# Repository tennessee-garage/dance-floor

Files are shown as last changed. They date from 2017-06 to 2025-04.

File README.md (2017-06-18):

# dance-floor
Code for various components of the LED disco dance floor

* [eagle](https://github.com/garthwebb/dance-floor/tree/master/eagle) - Eagle files for the PCBs used in this project
* [floor](https://github.com/garthwebb/dance-floor/tree/master/floor) - This code controls the light show on the dance floor
* poc_test - Proof of concept test code.
* [spi-buffer](https://github.com/garthwebb/dance-floor/tree/master/spi-buffer) - This code handles reading SPI weight data coming from the floor
* [square](https://github.com/garthwebb/dance-floor/tree/master/square) - This code run on the ATTiny in each square and manages the lights and weight sensors

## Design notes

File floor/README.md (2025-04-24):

# Floor Code



## Overview

The code in this directory controls all the lights on the floor as well as reads the weight data sent by the floor.

This code is intended to run on a Raspberry Pi with a special communication sheild that facilitates communication with the floor.  It is started via:
```bash
  python run-show.py
```
For development and testing, use the devserver driver. It allows you to run the code and preview a mock dance floor in a web browser.  It can be run via:
```bash
  python run-show.py --driver devserver
```

## Files/Directories

* **bin** - General executables
* **controller** - The main class, acts a framework for controllers and drivers
* **driver** - Different I/O drivers.  Currently they are `raspberry` for running on a Raspberry Pi and interfacing with its hardware, 'devserver' for development or `opc` (deprecated) for connecting to an existing Open GL server (`gl_server`) that simulates the floor.
* **opc-layouts** - Different OPC pixel layout files when using the opc driver.  These are used by `gl_server` to draw a representation of the floor.
* **processor** - Each file here generates different pixel patterns
* **run-show.py** - The main program that drives the dancefloor

## Setup

### Prerequisites

You'll need `poetry`. On a Mac with Homebrew, install with:

```
$ brew install poetry
```

For other options, see [the Poetry installation docs](https://python-poetry.org/docs/#installation).

### Developer setup

Install dependencies - one time, and whenever you change them:
```
$ poetry install
```

Then activate the virtual environment:
```
$ eval $(poetry env activate)
```

To run tests:

```
$ pytest
```

It is recommend you install `pre-commit` to take care of auto-formatting code.
```
$ brew install pre-commit
$ pre-commit install
```

### Production setup (Raspberry Pi)

1. Clone this repository
```bash
git clone git@github.com:tennessee-garage/dance-floor.git
```

2. [OPTIONAL] If you will run the code on a RaspberryPi, an SPI library is needed (If running in dev/virtual mode, SPI is not necessary)
```bash
git clone git@github.com:doceme/py-spidev.git
sudo apt-get install python-dev
cd py-spidev
sudo make install
```

3. Include the user that will run the code to groups that grant access to hardware ports
```bash
sudo usermod -aG spi disco
sudo usermod -aG dialout disco
```

4. Install poetry
```bash
curl -sSL https://install.python-poetry.org | python3 -
```

5. Install depencencies (from within the dance-floor repository)
```bash
cd floor
poetry install
```

## Running the code

Don't have a light up dance floor?  No problem!  You can see a visualization of the dance floor by running devserver.

1. Start the devserver:
```bash
cd floor
python run-show.py --driver devserver
```
2. Open two browser windows. The dance floor renders at this address:
   http://localhost:1979/

3. The controller renders here:
   http://0.0.0.0:1977/

## Writing a new processor

Different processors provide different ways to drive the floor LEDs. See README.md in the [processor folder](https://github.com/garthwebb/dance-floor/tree/master/floor/processor) for how to write a new processor.

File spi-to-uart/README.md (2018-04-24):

# SPI to UART

This is a simple program to read data coming in on SPI and transmit the data directly to UART.  It is unidirectional,
so does not read data from UART.  The data is not interpreted either.  it is transmitted byte by byte exactly as it
is received.

This is used to read the SPI values the squares are sending, and then send it out to an FTDI cable connected to a
computer.  If I wasn't too lazy to find and power up a Raspberry Pi I could probably write a script to read the SPI
port directly and print to terminal.

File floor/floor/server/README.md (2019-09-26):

# Dancefloor Server

This is a simple HTTP service that exposes a public API and control web page to the running dance floor. It also exposes a GUI control interface.

<!-- START doctoc generated TOC please keep comment here to allow auto update -->
<!-- DON'T EDIT THIS SECTION, INSTEAD RE-RUN doctoc TO UPDATE -->
**Table of Contents**  *generated with [DocToc](https://github.com/thlorenz/doctoc)*

- [GUI Frontend](#gui-frontend)
- [API](#api)
  - [`GET /api/status`](#get-apistatus)
  - [`POST /api/playlist/advance`](#post-apiplaylistadvance)
  - [`POST /api/playlist/previous`](#post-apiplaylistprevious)
  - [`POST /api/playlist/add`](#post-apiplaylistadd)
  - [`POST /api/playlist/stay`](#post-apiplayliststay)
  - [`DELETE /api/playlist/:position`](#delete-apiplaylistposition)
  - [`GET /api/playlists`](#get-apiplaylists)
  - [`GET /api/playlists/:name`](#get-apiplaylistsname)
  - [`POST /api/playlists/:name`](#post-apiplaylistsname)
  - [`POST /api/playlists/:name/activate`](#post-apiplaylistsnameactivate)
  - [`GET /api/tempo`](#get-apitempo)
  - [`POST /api/tempo`](#post-apitempo)
  - [`POST /api/tempo/nudge`](#post-apitemponudge)
  - [`GET /api/brightness`](#get-apibrightness)
  - [`POST /api/brightness`](#post-apibrightness)
  - [`GET /api/layers/:name`](#get-apilayersname)
  - [`PATCH /api/layers/:name`](#patch-apilayersname)
- [TODO](#todo)

<!-- END doctoc generated TOC please keep comment here to allow auto update -->

## GUI Frontend

The frontend is developed in a separate project. See source here: https://github.com/tennessee-garage/ddfui

For "production", we periodically check in a snapshot of this frontend to the `./static` folder here, so the RPi can serve it directly. These are the rough steps to follow:

```
### Build "production" frontend js, css, and assets.

$ cd ~/git/ddfui
$ npm install
$ yarn build

### Copy the built assets into this project.

$ cd ~/git/dance-floor/floor
$ ./bin/sync-frontend.sh ~/git/ddfui/build/
```

## API

### `GET /api/status`

Returns the current status.

**Request Arguments**

None.

**Response**

A structure consisting of:

* `playlist` (object): The current playlist; see `GET /api/playlist`.
* `tempo` (object): The current tempo; see `GET /api/tempo`.
* `processors` (array): A list of available processor, each an object consisting of:
  * `name` (string): The name of the processor.
* `brightness` (number): The global brightness, a number on `0.0 - 1.0`.

```json
{
  "playlist": {
    "current_position": 1,
    "millis_remaining": 2106,
    "queue": [
      {
        "args": {
          "animation": "Color train"
        },
        "duration": 5,
        "name": "animator"
      },
      {
        "args": {
          "text": "Bleep bloop fazz!"
        },
        "duration": 5,
        "name": "message"
      },
    ]
  },
  "processors": {
    "animator": {
      "name": "animator"
    },
    "message": {
      "name": "message"
    },
    "pulsar": {
      "name": "pulsar"
    }
  },
  "layers": {
    "overlay1": {
      "enabled": true,
      "processor_name": "CoolStep"
    },
    "overlay2": {
      "enabled": false,
      "processor_name": null
    }
  },
  "tempo": {
    "bpm": 120.0,
    "downbeat_millis": 1500861666019
  }
}```

### `GET /api/playlist`

Returns the current playlist.

**Request Arguments**

None.

**Response**

A playlist structure, consisting of:

* `current_position` (number): Current playlist position.
* `millis_remaining` (number): Number of milliseconds remaining on current item, `0` for indefinite.
* `queue` (object): The complete playlist, each item consisting of:
  * `name` (string): The processor name.
  * `duration` (number): The play duration, `0` for indefinite.
  * `args` (object; optional): Arguments to the processor.

```json
{
    "current_position": 1,
    "current": {
        "name": "message",
        "args": {
            "text": "Bleep bloop fazz!"
        },
        "duration": 5
    },
    "queue": [
        {
            "args": {
                "animation": "Color train"
            },
            "duration": 5,
            "name": "animator"
        },
        {
            "args": {
                "text": "Bleep bloop fazz!"
            },
            "duration": 5,
            "name": "message"
        },
        {
            "args": null,
            "duration": 5,
            "name": "raver_plaid"
        }
    ],
    "millis_remaining": 1492
}
```

### `POST /api/playlist/advance`

Advances the playlist to the next item, returning the playlist object.

**Request arguments**

None.

**Response**

The playlist object.

### `POST /api/playlist/previous`

Moves the playlist to the previous item, returning the playlist object.

**Request arguments**

None.

**Response**

The playlist object.

### `POST /api/playlist/add`

Adds a new item to the playlist, at the end of the playlist.

**Request arguments**

* `name` (string): The processor name.
* `duration` (number; optional): Play time in seconds; default of `0` for indefinite.
* `args` (string; optional): Processor-specific arguments.
* `next` (boolean; optional): If `true`, insert in next position rather than end. Implied when `immediate = true`.
* `immediate` (boolean; optional): If `true`, insert in next position _and_ advance immediately.

**Response**

The playlist object upon success; HTTP `400` on error.

### `POST /api/playlist/stay`

Cancel any auto-advance timeout on the current playlist item ("stay" on this processor).

**Request arguments**

None.

**Response**

The playlist object.

### `DELETE /api/playlist/:position`

Remove the playlist item at position `position`.

**Request arguments**

None.

**Response**

The playlist object upon success; HTTP `400` on error.

### `GET /api/playlists`

Lists _all_ playlists known to the system.

**Request arguments**

None.

**Response**

A dictionary of playlist items, keyed by a slug-like playlist name. Each value has the same format as `GET /api/playlist`.

### `GET /api/playlists/:name`

Fetches a single playlist, by slug-like playlist name.

**Request arguments**

None.

**Response**

The playlist object upon success; HTTP `404` if not found.

### `POST /api/playlists/:name`

Creates or updates a single playlist, by slug-like playlist name.

**Request arguments**

The request body should be a well-formed playlist object.

**Response**

The playlist object upon success; HTTP `400` upon failure.

### `POST /api/playlists/:name/activate`

Set this playlist as the current playlist.

**Request arguments**

None.

**Response**

The playlist object upon success; HTTP `404` if not found.

### `GET /api/tempo`

Get the current tempo settings.

**Request arguments**

None.

**Response**

The BPM information, consisting of:

* `bpm` (number): Beats per minute.
* `downbeat_millis` (number): Timestamp in milliseconds of the downbeat.

### `POST /api/tempo`

Set the current tempo.

**Request arguments**

* `bpm` (number): Beats per minute, as a number

**Response**

The BPM information.

### `POST /api/tempo/nudge`

Shift the BPM, downbeat, or both by a relative amount

**Request arguments**

* `bpm_delta` (number; optional): Value to add to or subtract from the current bpm.
* `downbeat_millis_delta` (number; optional): Value to add to or subtract from the current downbeat.

**Response**

The BPM information.

### `GET /api/brightness`

Get the global brightness of the floor, on a scale of 0.0 to 1.0.

**Response**

The current brightness.

```json
{
  "brightness": 0.7
}
```

### `POST /api/brightness`

Change the global brightness of the floor, on a scale of 0.0 to 1.0.

**Request arguments**

* `brightness` (number): The desired brightness, on a scale of `0.0` to `1.0`.

**Response**

Same as `GET /api/brightness`

### `GET /api/layers/:name`

Get details about a rendering layer.

**Response**

The layer's details.

```json
{
  "enabled": true,
  "processor_name": "CoolStep"
}
```

### `PATCH /api/layers/:name`

Adjust a rendering layer. Currently supports changing the processor, by patching the `processor_name` field.

**Request arguments**

* `processor_name` (string): The new processor name, or empty string to select no processor.
* `enabled` (boolean): Whether or not to enable the layer.

**Response**

Same as `GET /api/layers/:name`.

## TODO

Some improvements which should be made:

* Use a wsgi server in "production".
* Common error handling.
* Threadsafety around `Playlist` actions.
* Implement "add" and "delete" playlist operations.

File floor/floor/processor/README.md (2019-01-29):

# Processor Code

## Creating a new processor

1. Start with the skeleton for a processor:
```python
from floor.processor.base import Base

class YourPattern(Base):

    def __init__(self, **kwargs):
        super(YourPattern, self).__init__(**kwargs)
        # Set/initialize any state variables here

    def get_next_frame(self, context):
        # This gets called once every 1/fps seconds

        # Do something with list of context.weight values

        # Compute a list of RGB tuples, limit by COLOR_MAXIMUM
        # which gets set for you based on driver at object creation

        return pixels
```
2. Create code in `gen_next_frame` that creates a single frame of 64 RGB values.  The dance floor is 8 x 8 so if you want to work with x and y coordinates, you can do `pixels[x + y*8]` to index into the array as if it were multidimensional.
3. Import the processor in `processor/__init__.py`.
4. To test, call your class from the command line by giving the file name (make sure [gl_sever is running](https://github.com/garthwebb/dance-floor/blob/master/floor/README.md#running-the-code)):
```bash
python run-show.py --driver opc --processor your_class_file
```

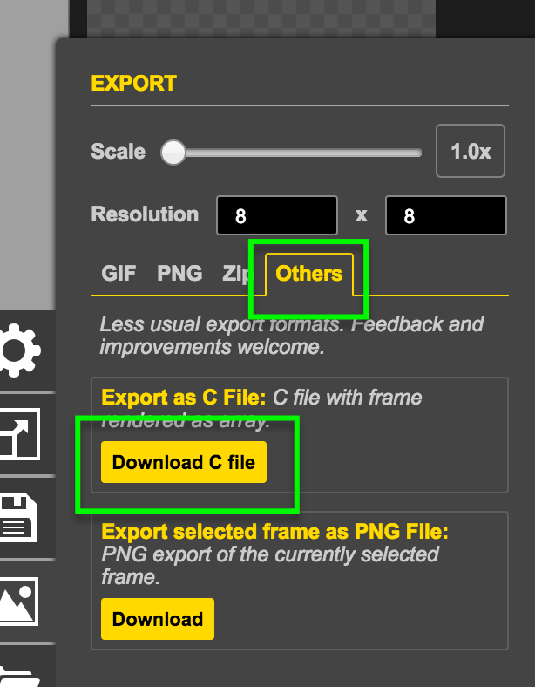
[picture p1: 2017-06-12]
wiki/img/Export C.png

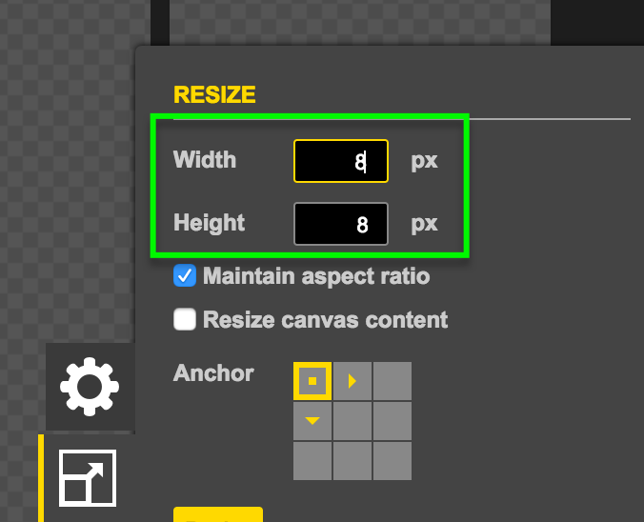
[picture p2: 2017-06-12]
wiki/img/Size-screenshot.png

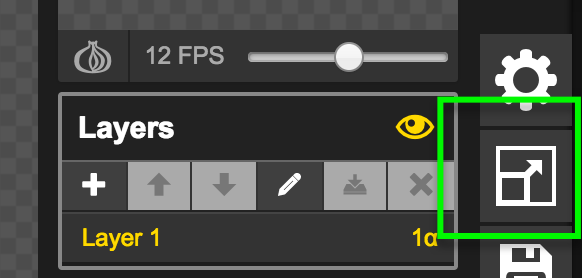
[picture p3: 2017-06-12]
wiki/img/Resize-screenshot.png

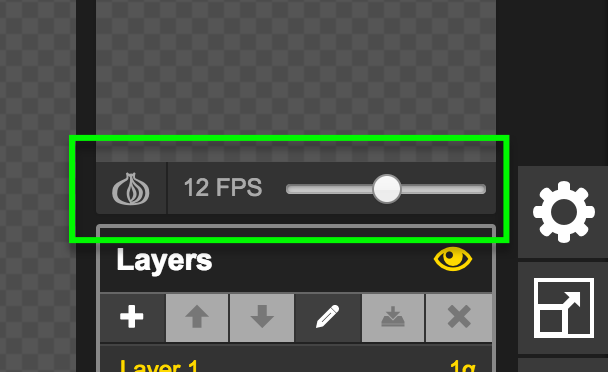
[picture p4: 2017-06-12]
wiki/img/fps-screenshot.png

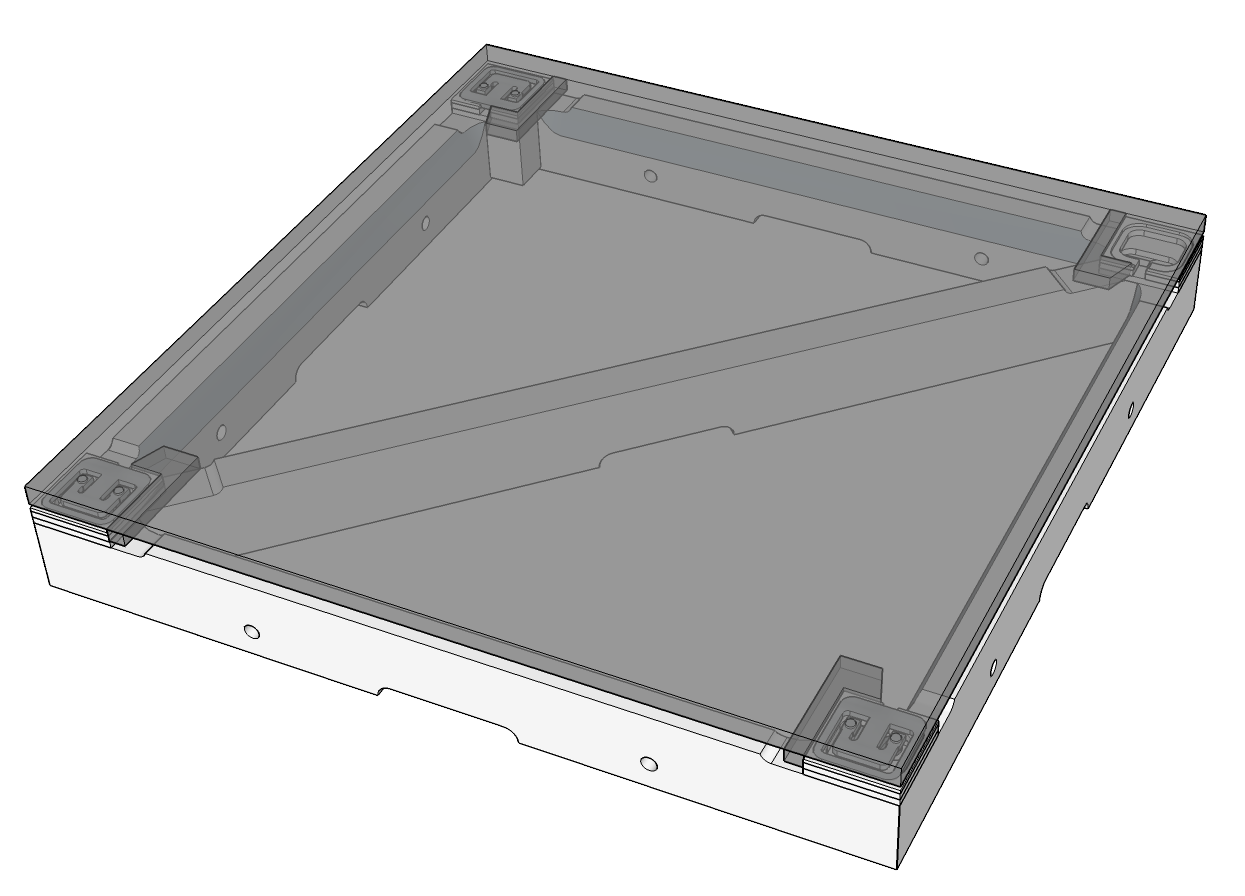
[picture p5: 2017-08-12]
models/Tile.png

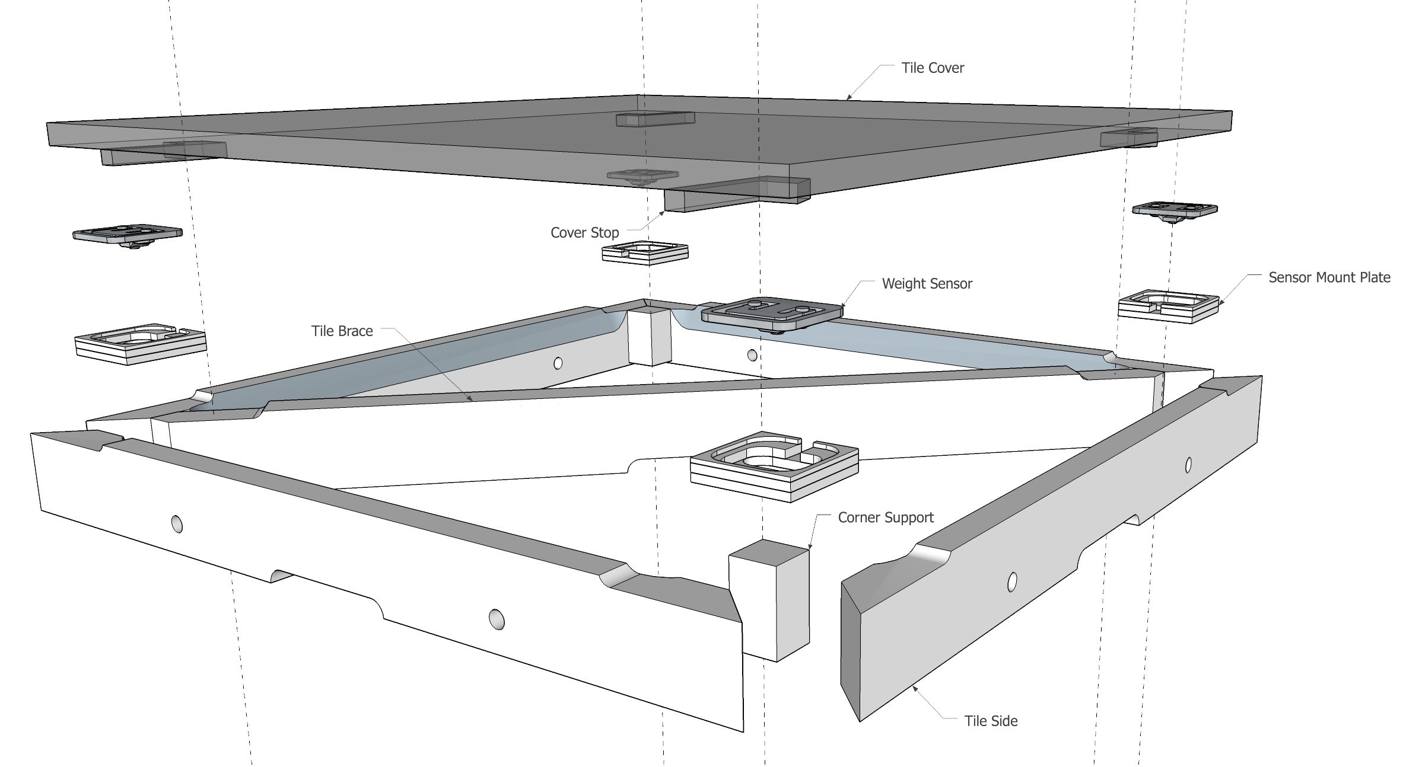
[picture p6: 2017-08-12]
models/Exploded View Tile.png

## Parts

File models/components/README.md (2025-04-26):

# 3D Models #

The *.skp files are models that were created in Sketchup of the different floor components.

The *.stl files are exports of these files from Sketchup, and can be previewed directly in Github, whereas the *.skp files will just be data/garbage

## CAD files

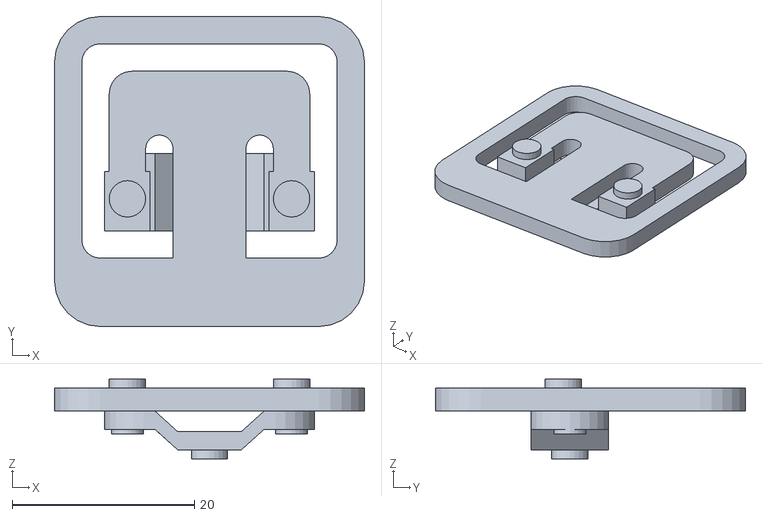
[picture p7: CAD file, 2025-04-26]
models/components/Weight Sensor.stl
34.0 x 34.0 x 8.75

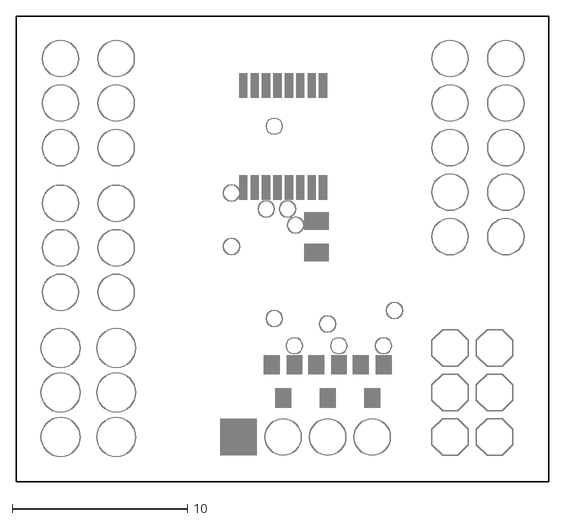
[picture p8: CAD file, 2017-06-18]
pcb/tile-controller/tile-controller-bottom.dxf
30.4 x 26.5

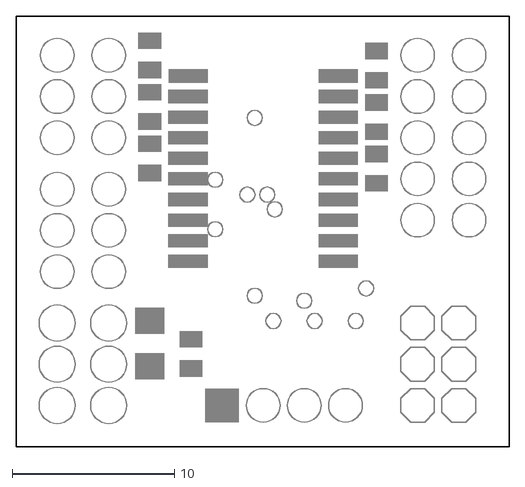
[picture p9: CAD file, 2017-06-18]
pcb/tile-controller/tile-controller.dxf
30.4 x 26.5

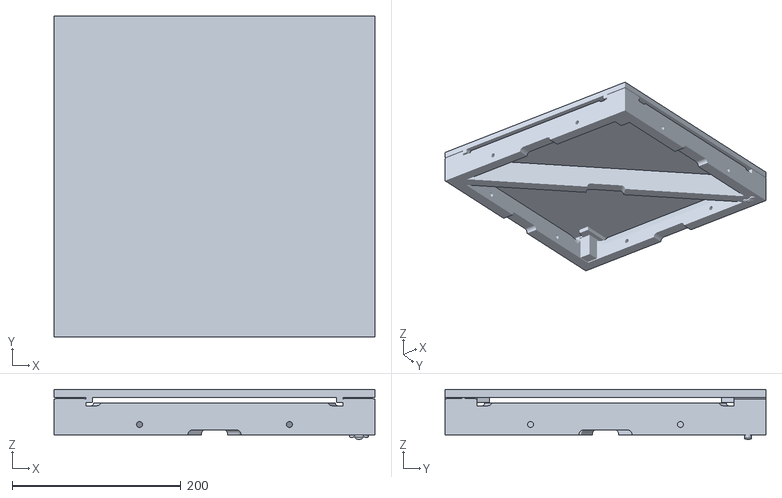
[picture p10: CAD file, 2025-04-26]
models/components/Single Tile.stl
381.0 x 381.0 x 59.7

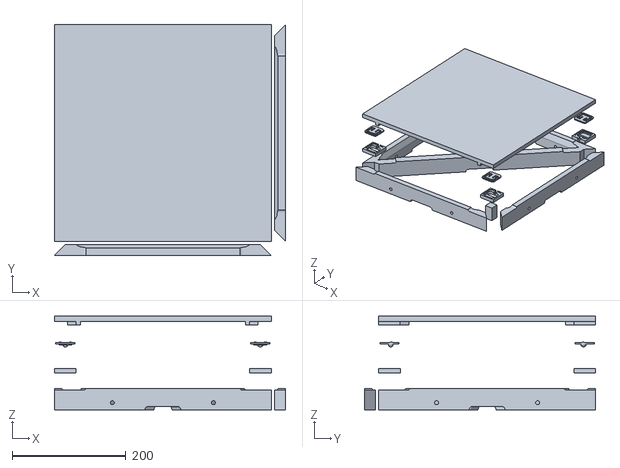
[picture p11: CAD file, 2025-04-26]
models/components/Exploded View Tile.stl
406.0 x 406.0 x 165.0

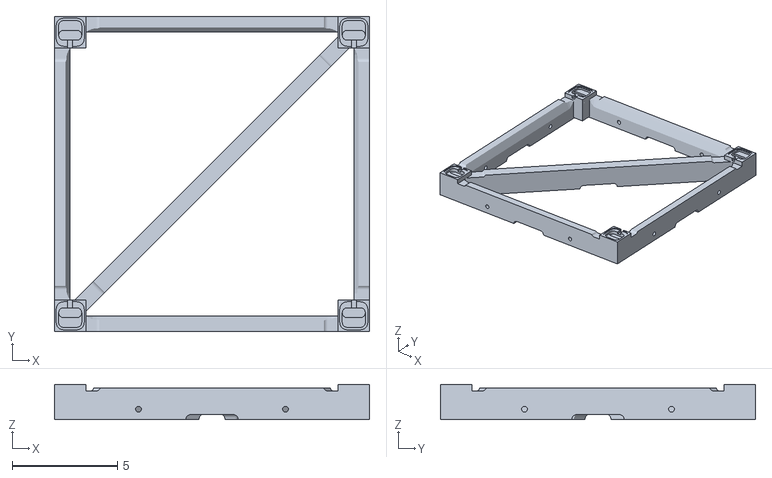
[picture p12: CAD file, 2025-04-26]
models/components/Tile Base.stl
15.0 x 15.0 x 1.69

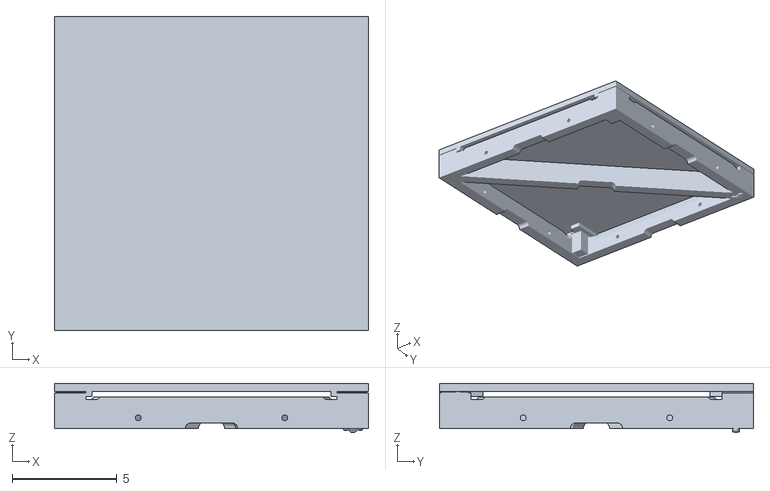
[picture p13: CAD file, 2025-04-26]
models/components/Tile.stl
15.0 x 15.0 x 2.35

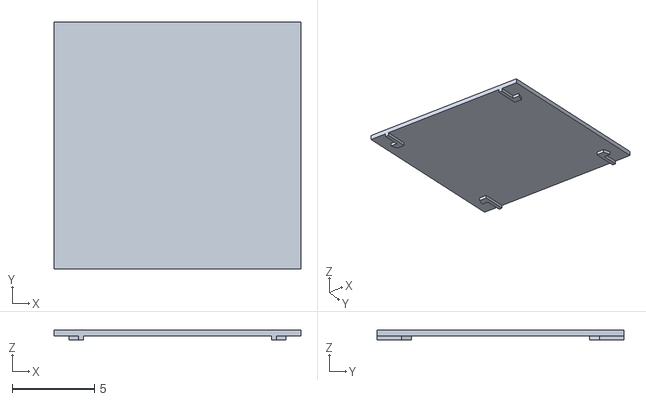
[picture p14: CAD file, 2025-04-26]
models/components/Tile Cover.stl
15.0 x 15.0 x 0.625

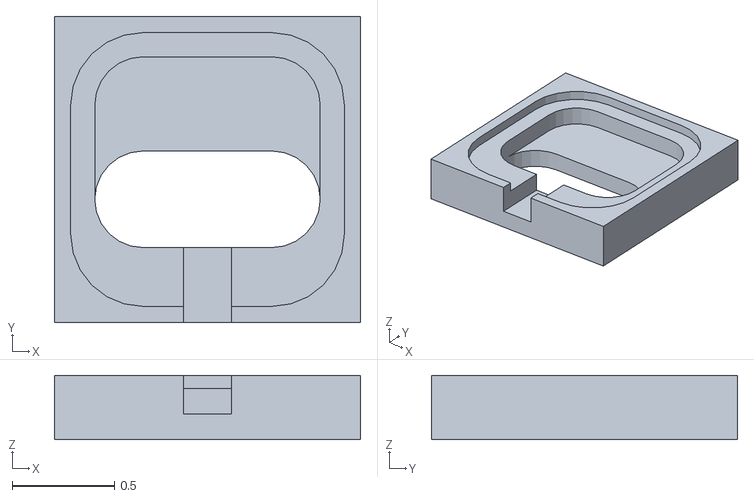
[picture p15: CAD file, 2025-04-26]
models/components/Weight Support.stl
1.50 x 1.50 x 0.313

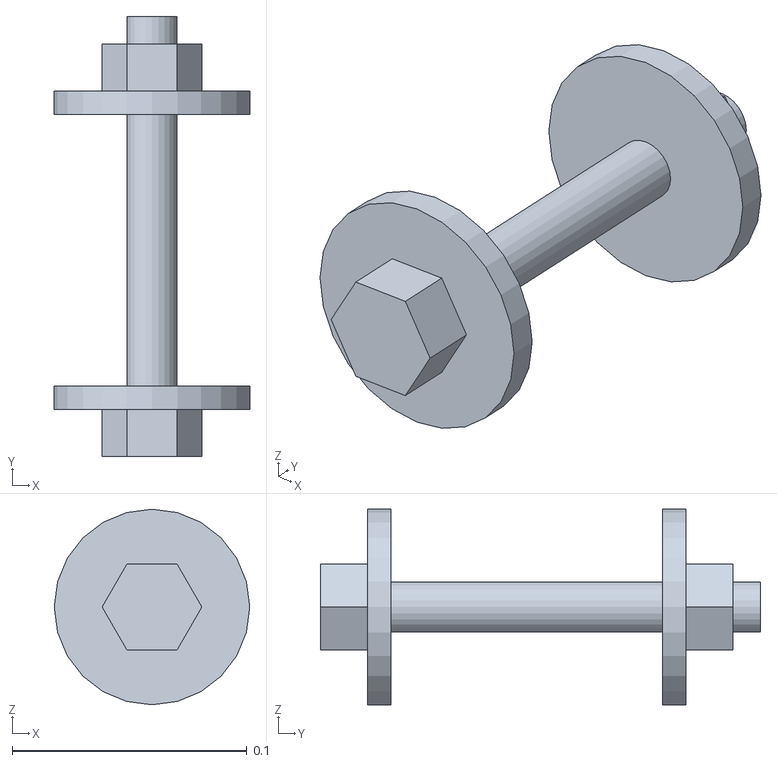
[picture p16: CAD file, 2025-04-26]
models/components/Hardware 1.4 Nuts Bolts Adjustable Length.stl
0.0833 x 0.187 x 0.0833

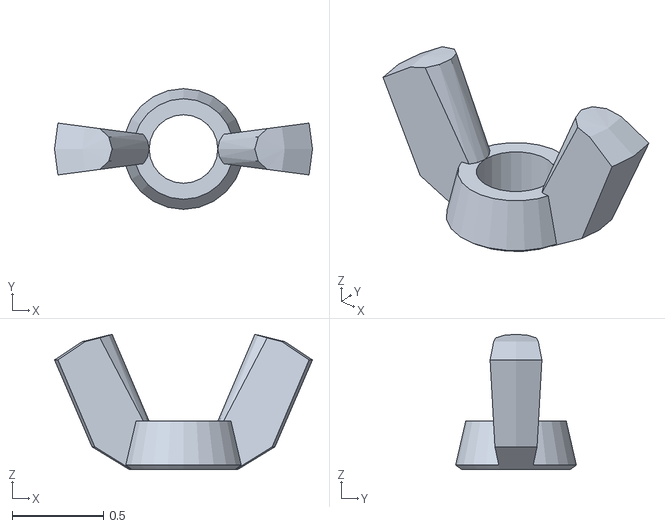
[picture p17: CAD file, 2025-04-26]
models/components/Wing Nut.stl
1.41 x 0.66 x 0.74

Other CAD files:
pcb/comm-board/comm-board.dxf
models/Floor Assembly.skp
models/Power Distribution.skp
models/components/Exploded View Tile.skp
models/components/Hardware 1.4 Nuts Bolts Adjustable Length.skp
models/components/Single tile.skp
models/components/Tile Base.skp
models/components/Tile Cover.skp
models/components/Tile.skp
models/components/Weight Sensor.skp
models/components/Weight Support.skp
models/components/Wing Nut.skp

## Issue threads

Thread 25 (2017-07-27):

Playlist management from web UI

mik3y, 2017-07-27:
(Filing this for tracking as I've got a branch in progress & would like to hear if I'm missing anything!)

Should be able to:
* List and add a new item from existing processors.
* Set optional args (like `text` for `message`).
* Set duration or infinite.
* Delete a playlist item.
* Reset to default state.

Playlist UI should also show a duration indicator for current item.

Closed 2019-09-26.

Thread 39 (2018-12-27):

Processor interface pixel format change?

mik3y, 2018-12-27:
Currently processors return pixels as a 3-tuple of `(red, green, blue)`, which are integers on `[0, self.max_value]`. `self.max_value` is a dynamic value within a processor, which can vary based on (a) the dynamic range of the show's driver, and (b) the current brightness called for by the controller.

I was thinking both (a) and (b) are leaky abstractions of sorts, since they're controller concepts that a "generic" processor shouldn't have to worry about. We could simplify processor code by moving these back to an unchanging absolute range, like `[0-255]` for 8-bit color.

As an unrelated thought, I also thought in the future it might be really interesting to support a mode where you can "stack" or layer processors, similar to e.g. layers in photoshop, where an alpha channel describes how much of the next layer beneath to blend.

Both of these combined: What do you think about changing the "pixel" return value to something like an absolute `(red, greed, blue, alpha)`; and consequently, move scaling currently accomplished by `max_value` into the `Controller`?

mik3y, 2018-12-27:
not sure if you get notifications on issue create, so just in case: yo @garthwebb !

mik3y, 2018-12-28:
Oh, a slight tweak on this idea, we could support _either_ 4-tuple `(r, g, b, a)` pixels, or 3-tuple `(r, g, b)` with implied alpha of 100% (for processors that don't care about alpha). In either case, r/g/b/a would all be on a standard range as in the other part of the proposal, like `[0.0, 1.0]` or `[0, 255]`.

garthwebb, 2018-12-28:
So the driver class _should_ be the thing that dictates what the max value is, and in fact it is, but it's plumbed through in a weird way right now.  Having the `max_value` field set and defined within the `Base` processor class is meant to make it so the 'processor shouldn't have to worry about' it.

I think the Base.__init__ should take a controller object and then `Base.max_value()` asks the controller what the max value is (rather than Controller pushing the value out to the processor as current).  The `Controller` should get its value from the `Driver` and modify it depending on the input it gets about dimming the floor.

I don't want to limit us to 8-bit color channels because it just can't do good fades since you get at best 256 steps if starting from full on.  Even then, the human eye is much more perceptive to lower luminosity levels, so it works out to ~128 steps (the top 128 you don't really notice).

I know we could get that back with the alpha channel, but that would only come into play for Processors that want to intentionally dim.  For processors that are varying in color over time the effect will be noticeable chunkiness at lower light levels.

If we really wanted to have a constant value for Processors, I'd advocate for 0.0 to 1.0 and then do the math to scale up in the driver.  However, I'd worry if the little RaspberryPi could handle 196 additional floating point calculations per frame.  Already with the Ripple pattern requesting 120 fps (it does look better) when running on the RaspPi it can't finish a frame in time.  As a side note, I think it would be good to make a performance pass at some point.

Finally, another angle to take if we start messing with pixel representation is to go to HSV.  We need RGB simply because it's the physical representation of the lighting, but its garbage to work with in Processors.  Almost always, you just want a color and you want to vary that color in a sane way.  Mixing R, G, B is not sane.

mik3y, 2018-12-29:
Ah, great points!

> If we really wanted to have a constant value for Processors, I'd advocate for 0.0 to 1.0 and then do the math to scale up in the driver. However, I'd worry if the little RaspberryPi could handle 196 additional floating point calculations per frame. Already with the Ripple pattern requesting 120 fps (it does look better) when running on the RaspPi it can't finish a frame in time. As a side note, I think it would be good to make a performance pass at some point.

My thoughts as well! One of the things I've wanted to do for a while is benchmark some of the existing processors, especially before making changes that could affect (or are suspected to improve) performance. Some of my recent changes to inject the clock now make this a lot easier (since we can call `get_next_frame` as fast as we want, with a fake clock)... lemme pause on the pixel idea here, write the benchmarker, and then see where we end up.

mik3y, 2019-05-25:
implemented in #46 - closing!

Closed 2019-05-25.

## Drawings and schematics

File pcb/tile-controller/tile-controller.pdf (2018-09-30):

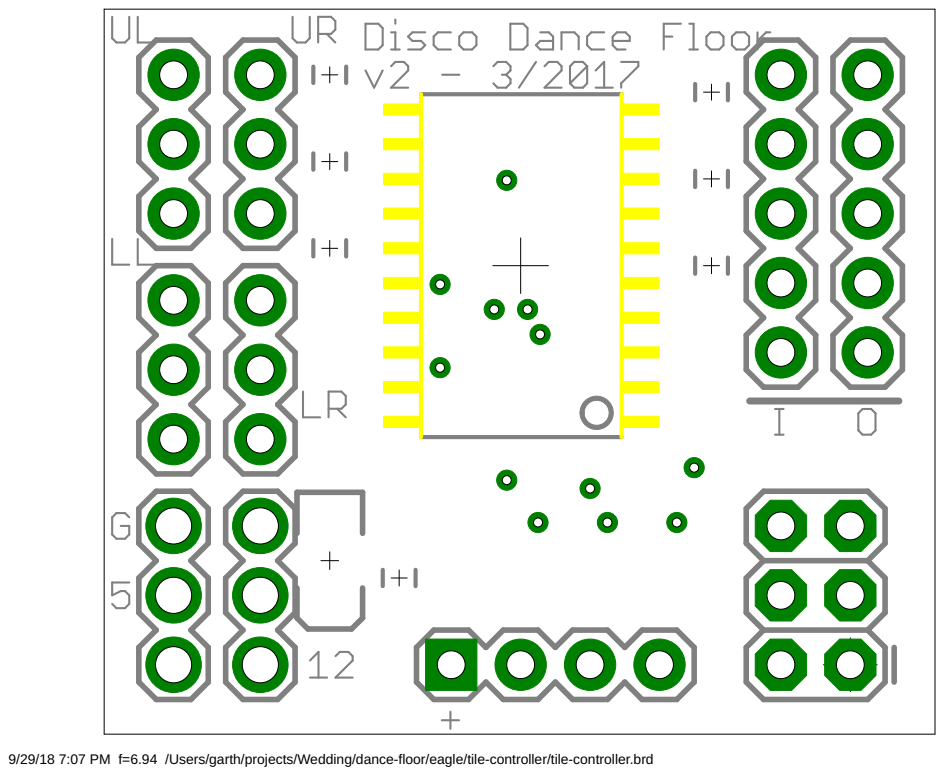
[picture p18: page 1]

9/29/18 7:07 PM f=6.94 /Users/garth/projects/Wedding/dance-floor/eagle/tile-controller/tile-controller.brd

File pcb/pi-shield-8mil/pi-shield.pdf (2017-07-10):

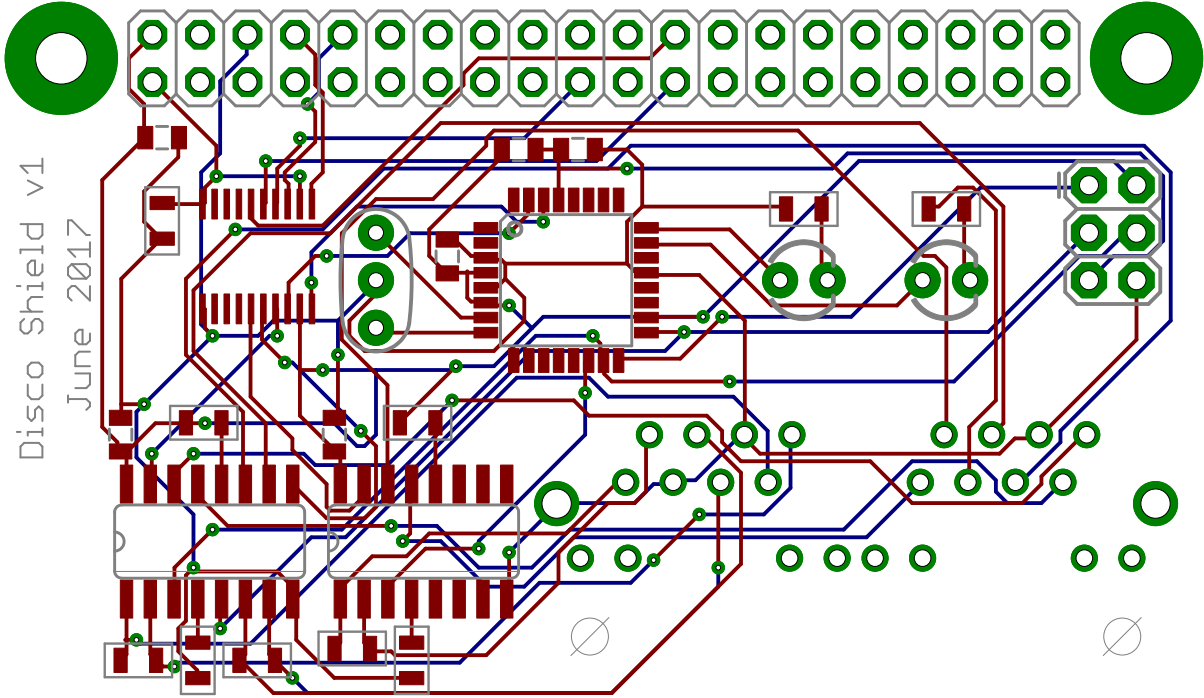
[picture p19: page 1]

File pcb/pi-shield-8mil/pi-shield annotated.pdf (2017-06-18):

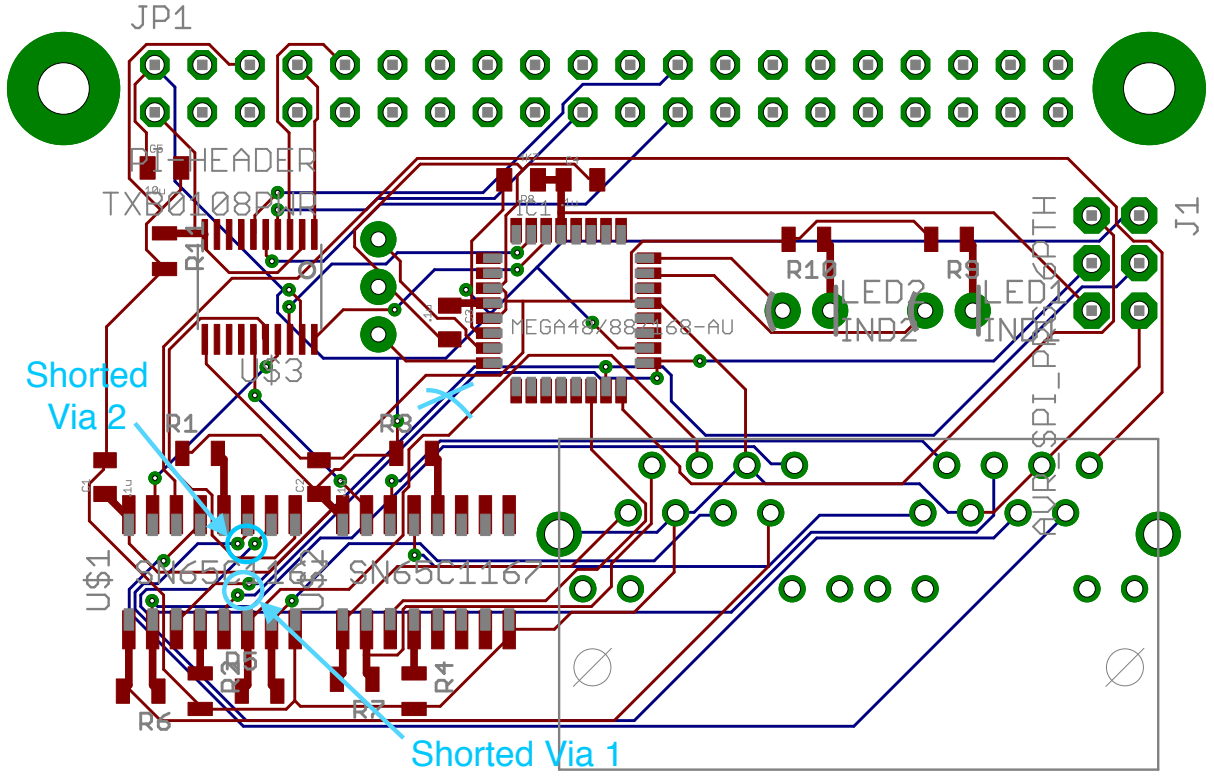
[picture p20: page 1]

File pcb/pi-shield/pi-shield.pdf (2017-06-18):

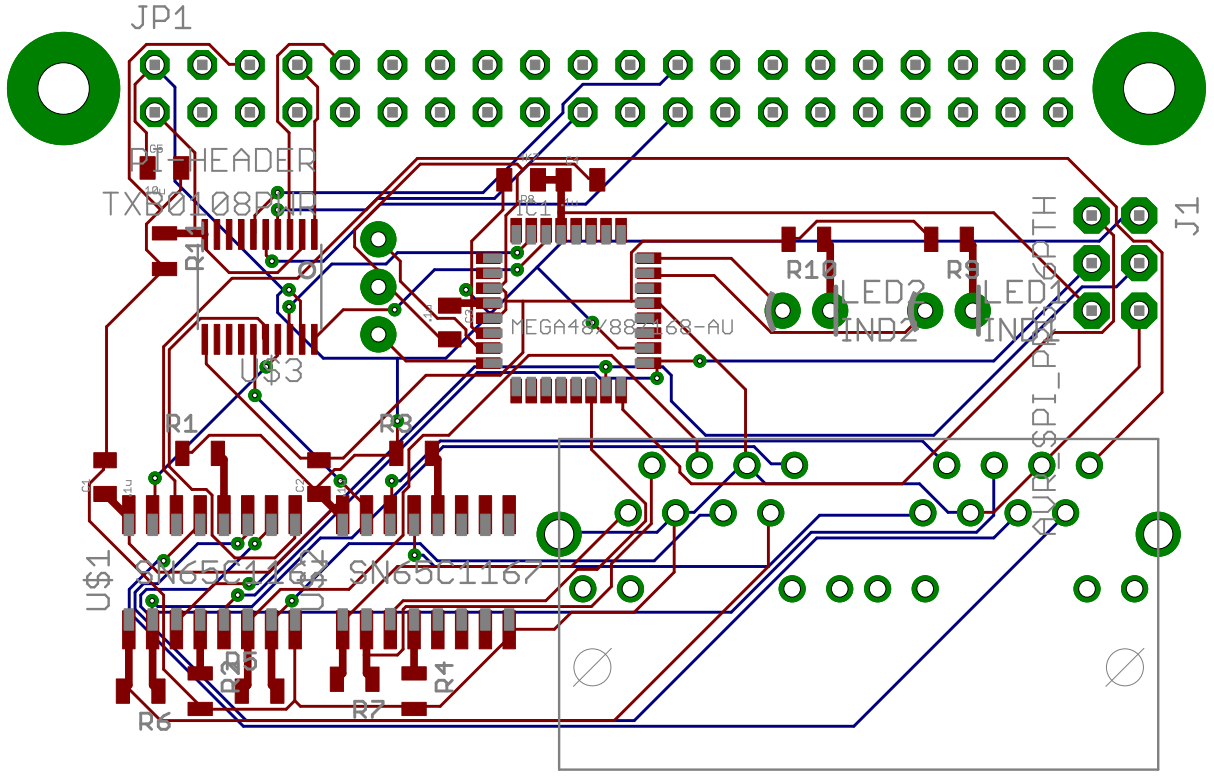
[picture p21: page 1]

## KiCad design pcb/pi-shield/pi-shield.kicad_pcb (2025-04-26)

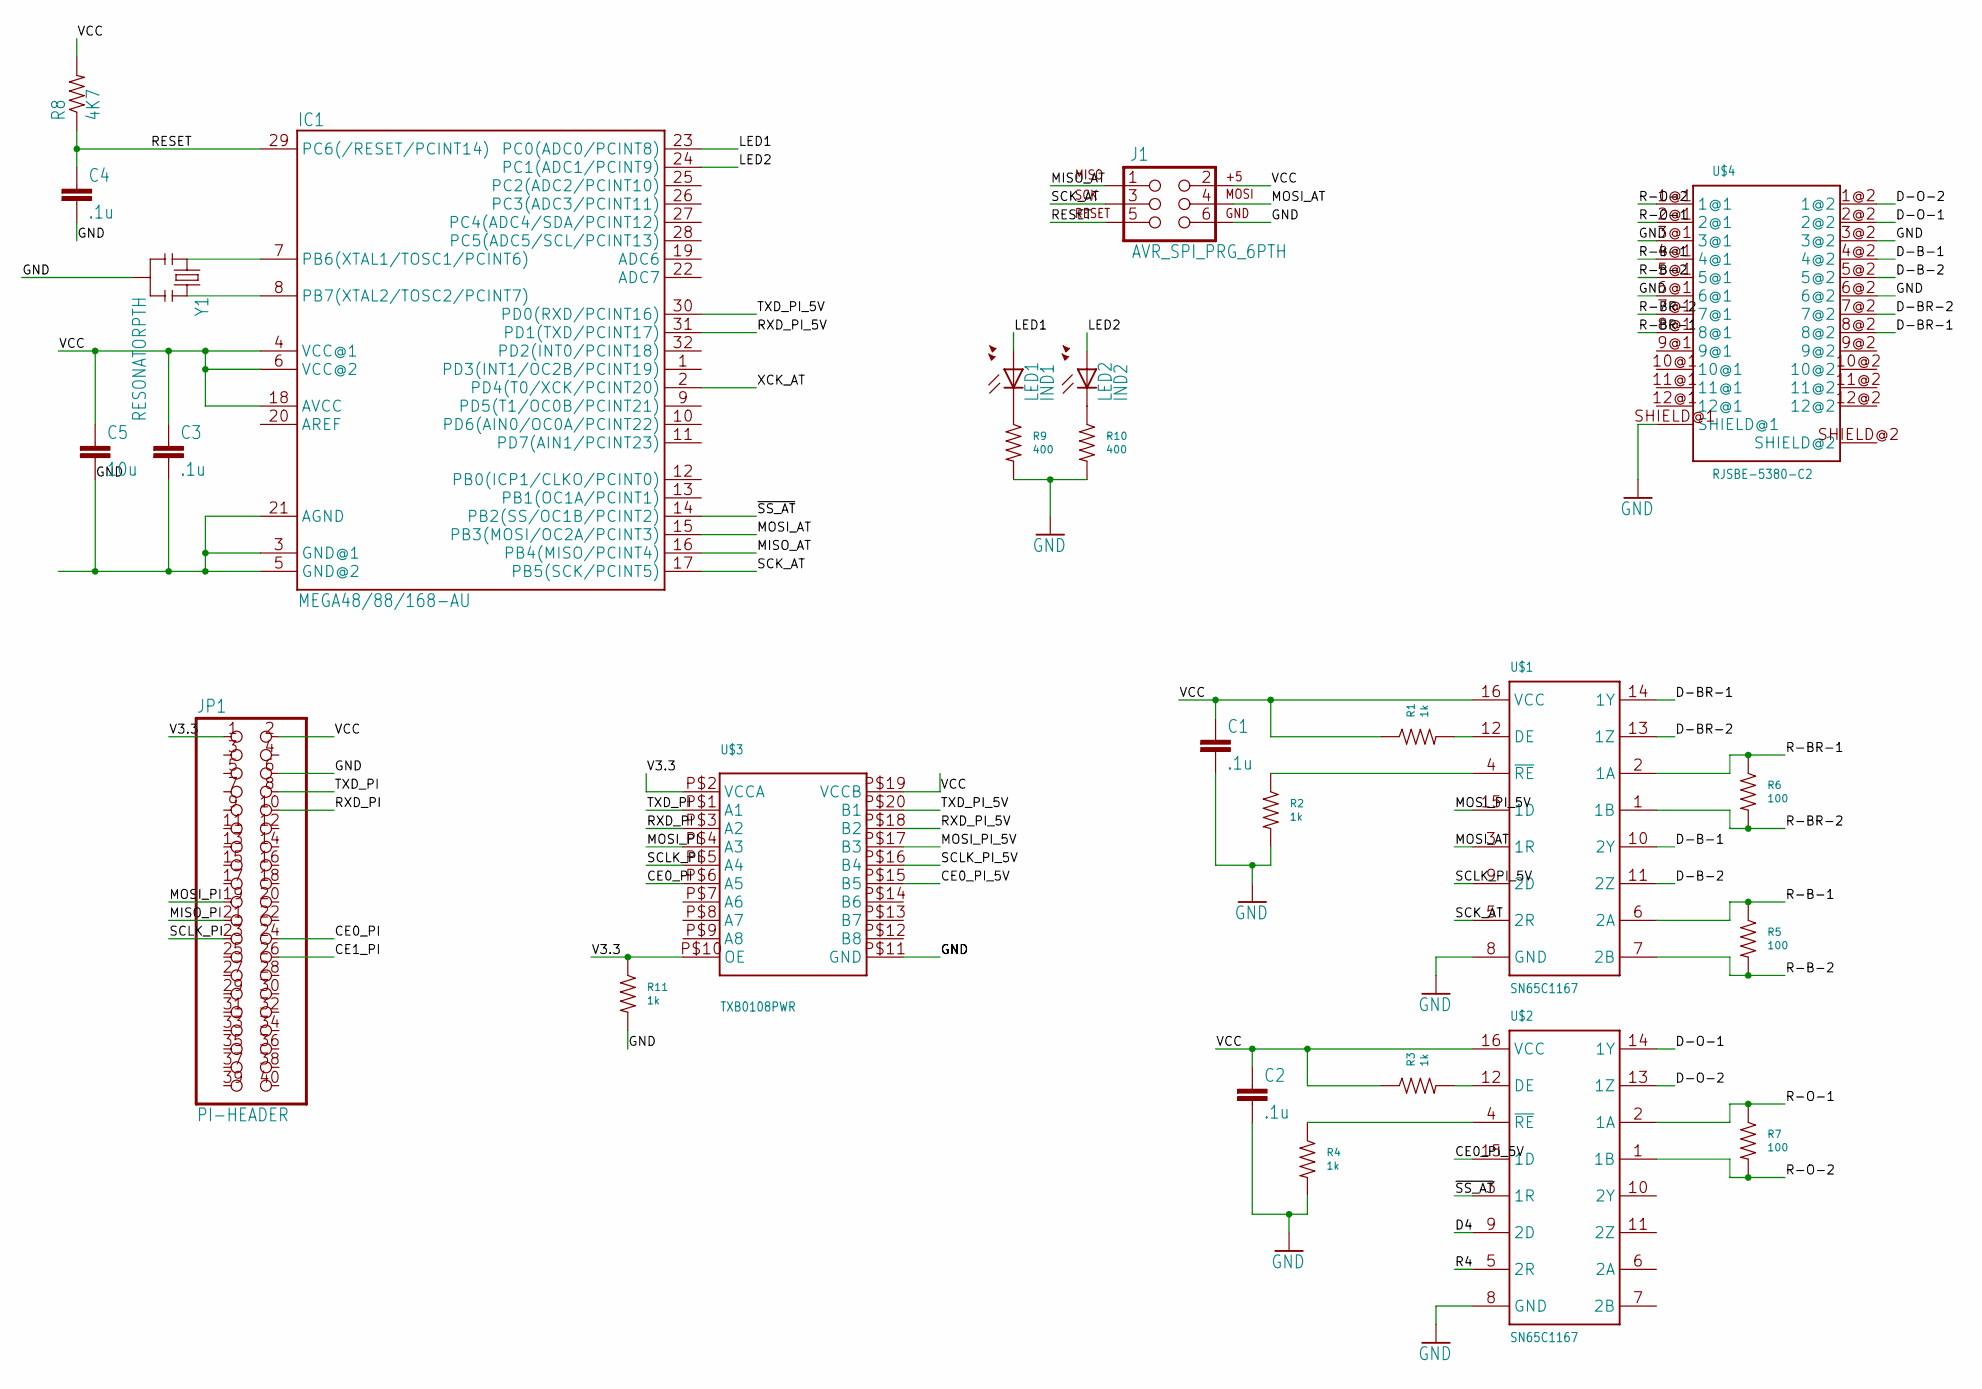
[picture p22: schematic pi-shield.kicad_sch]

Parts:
C1, C2, C3, C4: .1u; 0805
C5: 10u; 0805
IC1: MEGA48/88/168-AU; TQFP32-08
J1: AVR_SPI_PRG_6PTH; 2X3
JP1: PI-HEADER; 2X20
LED1: IND1; LED3MM
LED2: IND2; LED3MM
R1, R2, R3, R4, R11: 1k; R0805
R5, R6, R7: 100; R0805
R8: 4K7; 0805
R9, R10: 400; R0805
U$1, U$2: SN65C1167; SOP-16
U$3: TXB0108PWR; TSSOP20
U$4: RJSBE-5380-C2
Y1: RESONATORPTH; RESONATOR-PTH

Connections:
CE0_PI: JP1.24, U$3.P$6 (A5)
CE0_PI_5V: U$2.15 (1D), U$3.P$15 (B5)
CE1_PI: JP1.26
D4: U$2.9 (2D)
D-B-1: U$1.10 (2Y), U$4.4@2
D-B-2: U$1.11 (2Z), U$4.5@2
D-BR-1: U$1.14 (1Y), U$4.8@2
D-BR-2: U$1.13 (1Z), U$4.7@2
D-O-1: U$2.14 (1Y), U$4.2@2
D-O-2: U$2.13 (1Z), U$4.1@2
GND: C1.2, C2.2, C3.2, C4.2, C5.2, IC1.3 (GND@1), IC1.5 (GND@2), IC1.21 (AGND), J1.6, JP1.6, R2.P$2, R4.P$2, R9.P$2, R10.P$2, R11.P$2, U$1.8 (GND), U$2.8 (GND), U$3.P$11 (GND), U$4.3@1, U$4.3@2, U$4.6@1, U$4.6@2, U$4.SHIELD@1, Y1.2
LED1: IC1.23 (PC0(ADC0/PCINT8)), LED1.A
LED2: IC1.24 (PC1(ADC1/PCINT9)), LED2.A
MISO_AT: IC1.16 (PB4(MISO/PCINT4)), J1.1
MISO_PI: JP1.21
MOSI_AT: IC1.15 (PB3(MOSI/OC2A/PCINT3)), J1.4, U$1.3 (1R)
MOSI_PI: JP1.19, U$3.P$4 (A3)
MOSI_PI_5V: U$1.15 (1D), U$3.P$17 (B3)
unnamed: R1.P$2, U$1.12 (DE)
unnamed: R2.P$1, U$1.4 (~RE)
unnamed: R3.P$2, U$2.12 (DE)
unnamed: R4.P$1, U$2.4 (~RE)
unnamed: LED1.K (C), R9.P$1
unnamed: LED2.K (C), R10.P$1
unnamed: IC1.7 (PB6(XTAL1/TOSC1/PCINT6)), Y1.1
unnamed: IC1.8 (PB7(XTAL2/TOSC2/PCINT7)), Y1.3
R4: U$2.5 (2R)
R-B-1: R5.P$1, U$1.6 (2A), U$4.4@1
R-B-2: R5.P$2, U$1.7 (2B), U$4.5@1
R-BR-1: R6.P$1, U$1.2 (1A), U$4.8@1
R-BR-2: R6.P$2, U$1.1 (1B), U$4.7@1
R-O-1: R7.P$1, U$2.2 (1A), U$4.2@1
R-O-2: R7.P$2, U$2.1 (1B), U$4.1@1
RESET: C4.1, IC1.29 (PC6(/RESET/PCINT14)), J1.5, R8.1
RXD_PI: JP1.10, U$3.P$3 (A2)
RXD_PI_5V: IC1.31 (PD1(TXD/PCINT17)), U$3.P$18 (B2)
SCK_AT: IC1.17 (PB5(SCK/PCINT5)), J1.3, U$1.5 (2R)
SCLK_PI: JP1.23, U$3.P$5 (A4)
SCLK_PI_5V: U$1.9 (2D), U$3.P$16 (B4)
TXD_PI: JP1.8, U$3.P$1 (A1)
TXD_PI_5V: IC1.30 (PD0(RXD/PCINT16)), U$3.P$20 (B1)
V3.3: JP1.1, R11.P$1, U$3.P$2 (VCCA), U$3.P$10 (OE)
VCC: C1.1, C2.1, C3.1, C5.1, IC1.4 (VCC@1), IC1.6 (VCC@2), IC1.18 (AVCC), J1.2, JP1.2, R1.P$1, R3.P$1, R8.2, U$1.16 (VCC), U$2.16 (VCC), U$3.P$19 (VCCB)
XCK_AT: IC1.2 (PD4(T0/XCK/PCINT20))
~SS_AT: IC1.14 (PB2(SS/OC1B/PCINT2)), U$2.3 (1R)

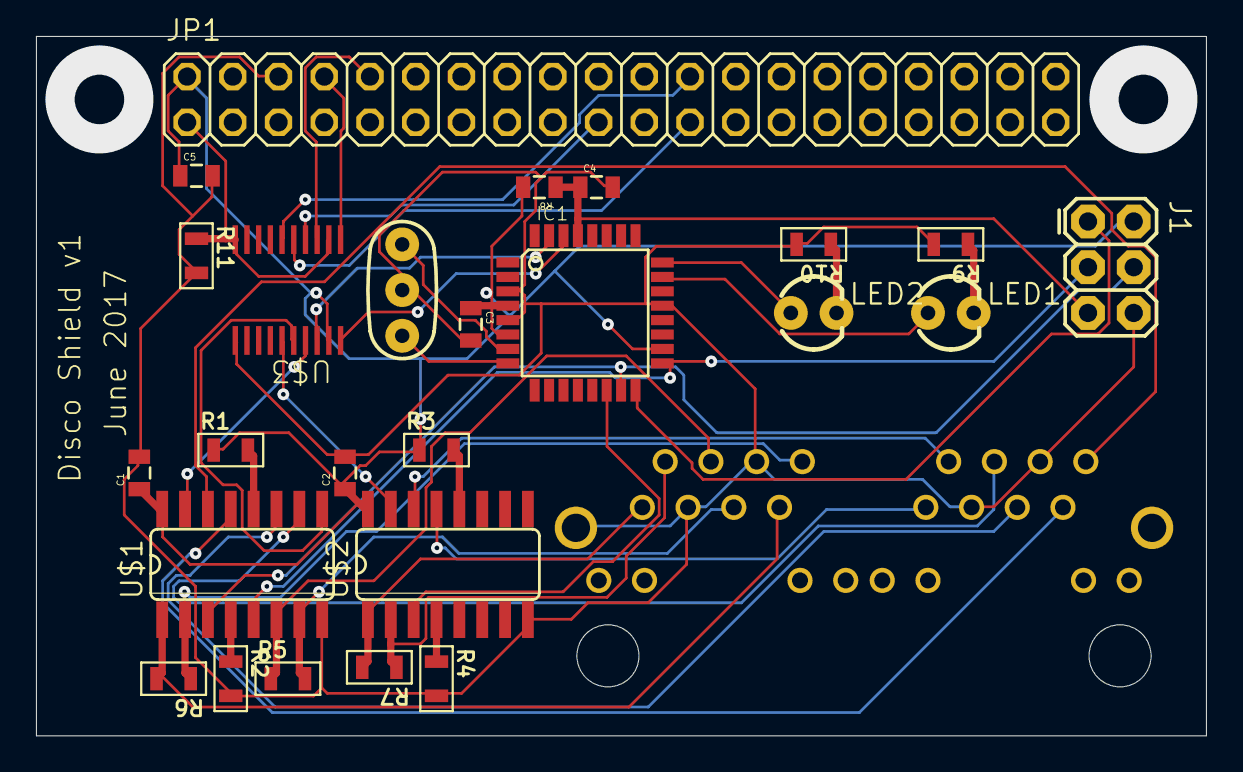
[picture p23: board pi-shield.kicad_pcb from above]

Board: 2 copper layers, 65.0 x 38.9 mm, 26 parts (0 on the bottom side), 40 nets.

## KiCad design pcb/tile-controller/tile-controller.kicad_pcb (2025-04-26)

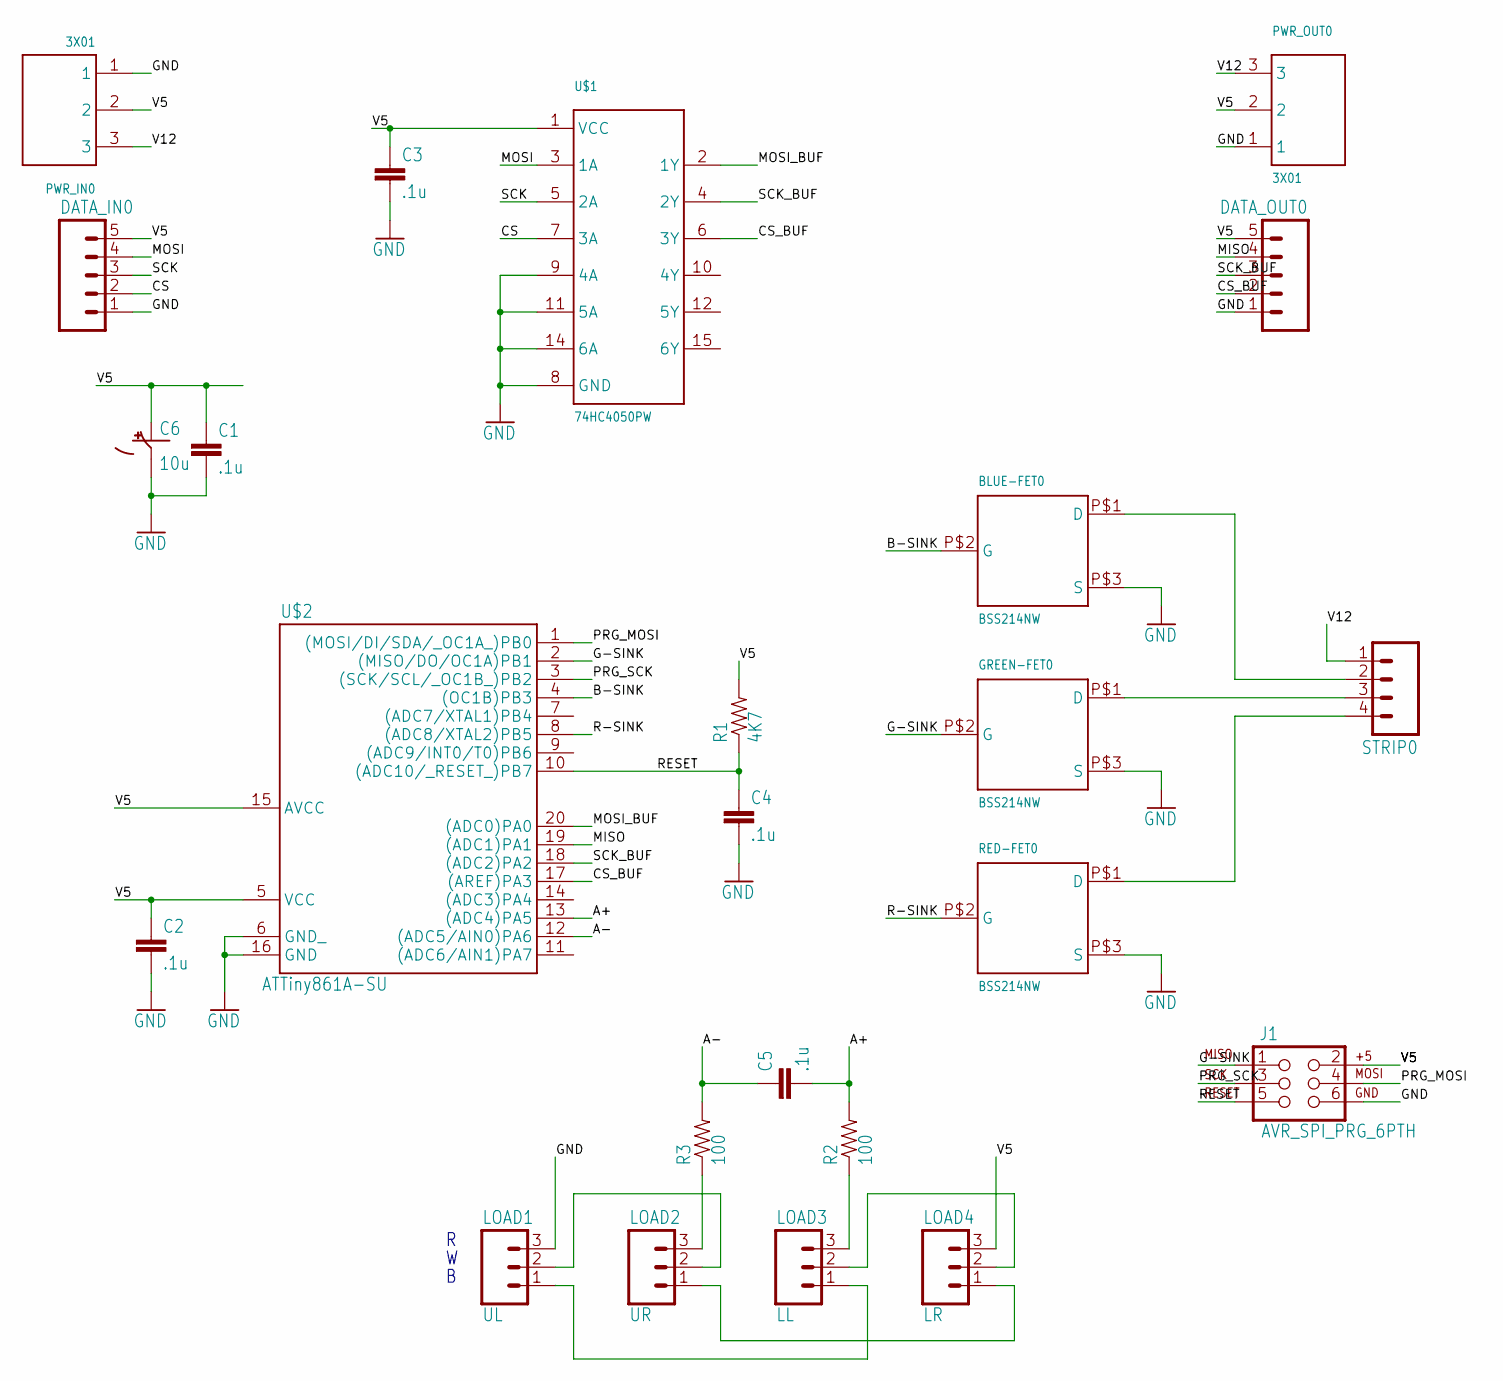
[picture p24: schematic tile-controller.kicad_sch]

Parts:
BLUE-FET0: BSS214NW; SOT-323
C1, C2, C3, C4, C5: .1u; 0805
C6: 10u; EIA3216
DATA_IN0: M05PTH; 1X05
DATA_OUT0: M05PTH; 1X05
GREEN-FET0: BSS214NW; SOT-323
J1: AVR_SPI_PRG_6PTH; 2X3
LOAD1: UL; 1X03
LOAD2: UR; 1X03
LOAD3: LL; 1X03
LOAD4: LR; 1X03
PWR_IN0: 3X01; 3X01-18AWG
PWR_OUT0: 3X01; 3X01-18AWG
R1: 4K7; 0805
R2, R3: 100; 0805
RED-FET0: BSS214NW; SOT-323
STRIP0: M04PTH; 1X04
U$1: 74HC4050PW; TSSOP16.2
U$2: ATTiny861A-SU; SO20L$

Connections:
A+: C5.2, R2.2, U$2.13 ((ADC4)PA5)
A-: C5.1, R3.2, U$2.12 ((ADC5/AIN0)PA6)
B-SINK: BLUE-FET0.P$2 (G), U$2.4 ((OC1B)PB3)
CS: DATA_IN0.2, U$1.7 (3A)
CS_BUF: DATA_OUT0.2, U$1.6 (3Y), U$2.17 ((AREF)PA3)
G-SINK: GREEN-FET0.P$2 (G), J1.1, U$2.2 ((MISO/DO/OC1A)PB1)
GND: BLUE-FET0.P$3 (S), C1.2, C2.2, C3.2, C4.2, C6.C (-), DATA_IN0.1, DATA_OUT0.1, GREEN-FET0.P$3 (S), J1.6, LOAD1.3, PWR_IN0.1, PWR_OUT0.1, RED-FET0.P$3 (S), U$1.8 (GND), U$1.9 (4A), U$1.11 (5A), U$1.14 (6A), U$2.6 (GND_), U$2.16 (GND)
MISO: DATA_OUT0.4, U$2.19 ((ADC1)PA1)
MOSI: DATA_IN0.4, U$1.3 (1A)
MOSI_BUF: U$1.2 (1Y), U$2.20 ((ADC0)PA0)
unnamed: LOAD1.1, LOAD3.1
unnamed: LOAD2.1, LOAD4.1
unnamed: GREEN-FET0.P$1 (D), STRIP0.3
unnamed: BLUE-FET0.P$1 (D), STRIP0.2
unnamed: RED-FET0.P$1 (D), STRIP0.4
unnamed: LOAD1.2, LOAD2.2
unnamed: LOAD3.2, LOAD4.2
PRG_MOSI: J1.4, U$2.1 ((MOSI/DI/SDA/_OC1A_)PB0)
PRG_SCK: J1.3, U$2.3 ((SCK/SCL/_OC1B_)PB2)
R-SINK: RED-FET0.P$2 (G), U$2.8 ((ADC8/XTAL2)PB5)
RESET: C4.1, J1.5, R1.1, U$2.10 ((ADC10/_RESET_)PB7)
SCK: DATA_IN0.3, U$1.5 (2A)
SCK_BUF: DATA_OUT0.3, U$1.4 (2Y), U$2.18 ((ADC2)PA2)
V5: C1.1, C2.1, C3.1, C6.A (+), DATA_IN0.5, DATA_OUT0.5, J1.2, LOAD4.3, PWR_IN0.2, PWR_OUT0.2, R1.2, U$1.1 (VCC), U$2.5 (VCC), U$2.15 (AVCC)
V12: PWR_IN0.3, PWR_OUT0.3, STRIP0.1
_1: LOAD2.3, R3.1
_2: LOAD3.3, R2.1

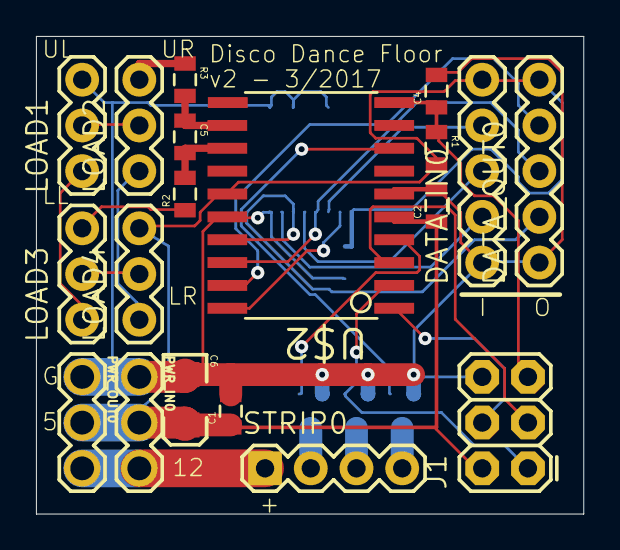
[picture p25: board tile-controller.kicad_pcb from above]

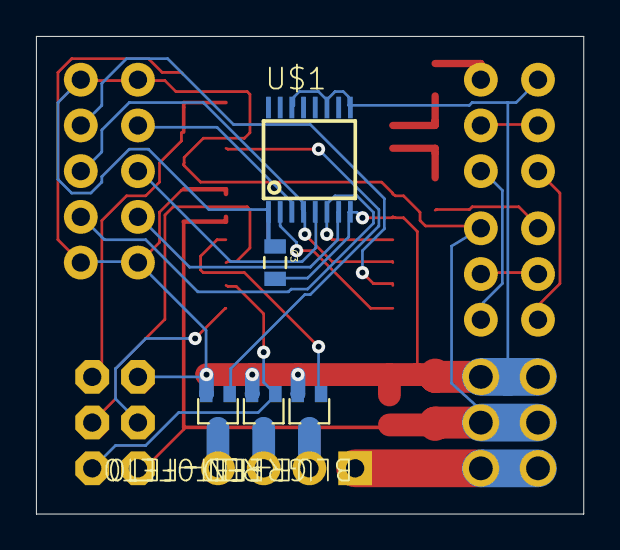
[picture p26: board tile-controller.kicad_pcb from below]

Board: 2 copper layers, 30.4 x 26.5 mm, 24 parts (5 on the bottom side), 27 nets.

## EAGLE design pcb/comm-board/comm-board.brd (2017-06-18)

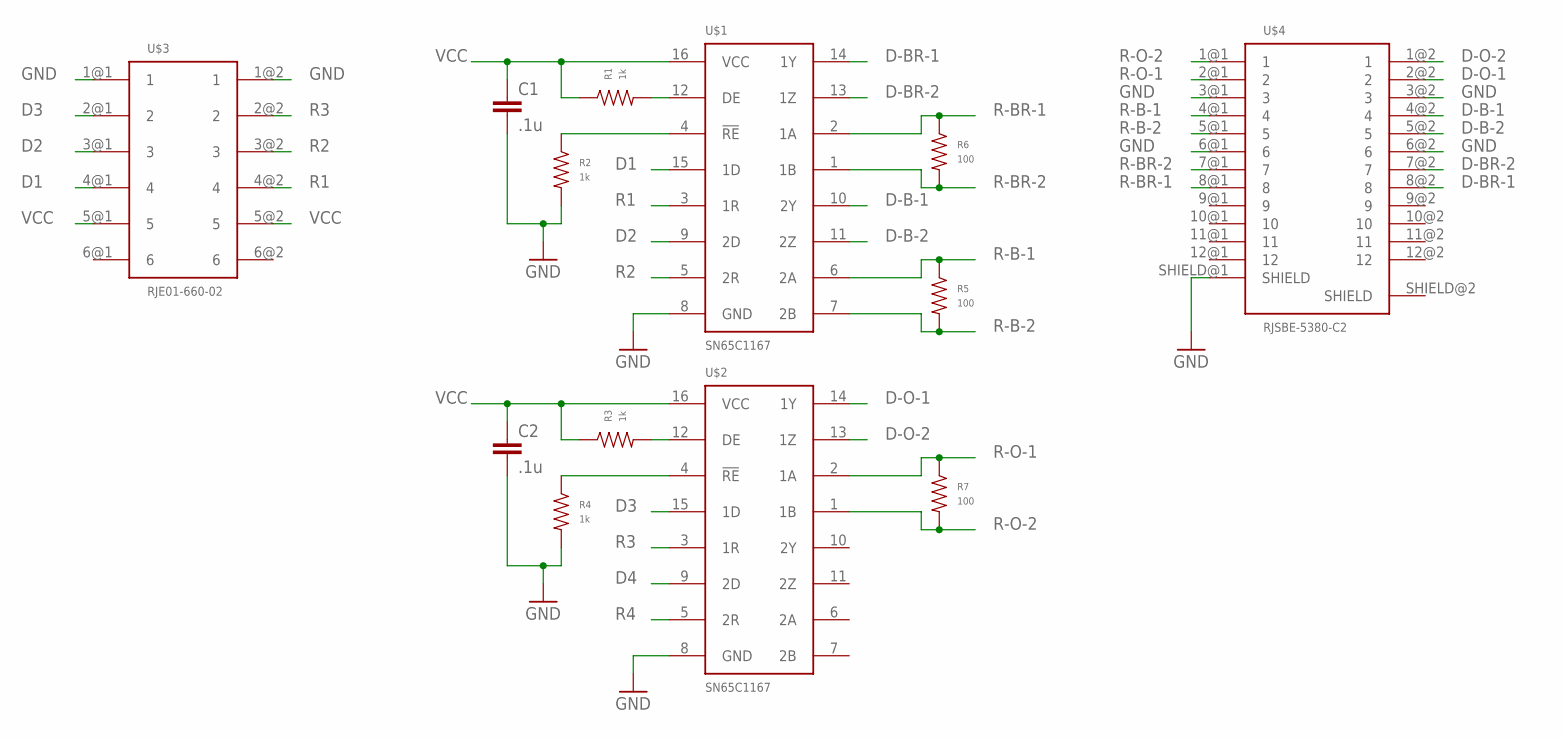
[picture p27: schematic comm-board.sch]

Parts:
C1, C2: .1u; 0805
R1, R2, R3, R4: 1k; R0805
R5, R6, R7: 100; R0805
U$1, U$2: SN65C1167; SOP-16
U$3: RJE01-660-02
U$4: RJSBE-5380-C2

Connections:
D1: U$1.15 (1D), U$3.4@1 (4)
D2: U$1.9 (2D), U$3.3@1 (3)
D3: U$2.15 (1D), U$3.2@1 (2)
D4: U$2.9 (2D)
D-B-1: U$1.10 (2Y), U$4.4@2 (4)
D-B-2: U$1.11 (2Z), U$4.5@2 (5)
D-BR-1: U$1.14 (1Y), U$4.8@2 (8)
D-BR-2: U$1.13 (1Z), U$4.7@2 (7)
D-O-1: U$2.14 (1Y), U$4.2@2 (2)
D-O-2: U$2.13 (1Z), U$4.1@2 (1)
GND: C1.2, C2.2, R2.P$2, R4.P$2, U$1.8 (GND), U$2.8 (GND), U$3.1@1 (1), U$3.1@2 (1), U$4.3@1 (3), U$4.3@2 (3), U$4.6@1 (6), U$4.6@2 (6), U$4.SHIELD@1 (SHIELD)
unnamed: R1.P$2, U$1.12 (DE)
unnamed: R2.P$1, U$1.4 (!RE)
unnamed: R3.P$2, U$2.12 (DE)
unnamed: R4.P$1, U$2.4 (!RE)
R1: U$1.3 (1R), U$3.4@2 (4)
R2: U$1.5 (2R), U$3.3@2 (3)
R3: U$2.3 (1R), U$3.2@2 (2)
R4: U$2.5 (2R)
R-B-1: R5.P$1, U$1.6 (2A), U$4.4@1 (4)
R-B-2: R5.P$2, U$1.7 (2B), U$4.5@1 (5)
R-BR-1: R6.P$1, U$1.2 (1A), U$4.8@1 (8)
R-BR-2: R6.P$2, U$1.1 (1B), U$4.7@1 (7)
R-O-1: R7.P$1, U$2.2 (1A), U$4.2@1 (2)
R-O-2: R7.P$2, U$2.1 (1B), U$4.1@1 (1)
VCC: C1.1, C2.1, R1.P$1, R3.P$1, U$1.16 (VCC), U$2.16 (VCC), U$3.5@1 (5), U$3.5@2 (5)

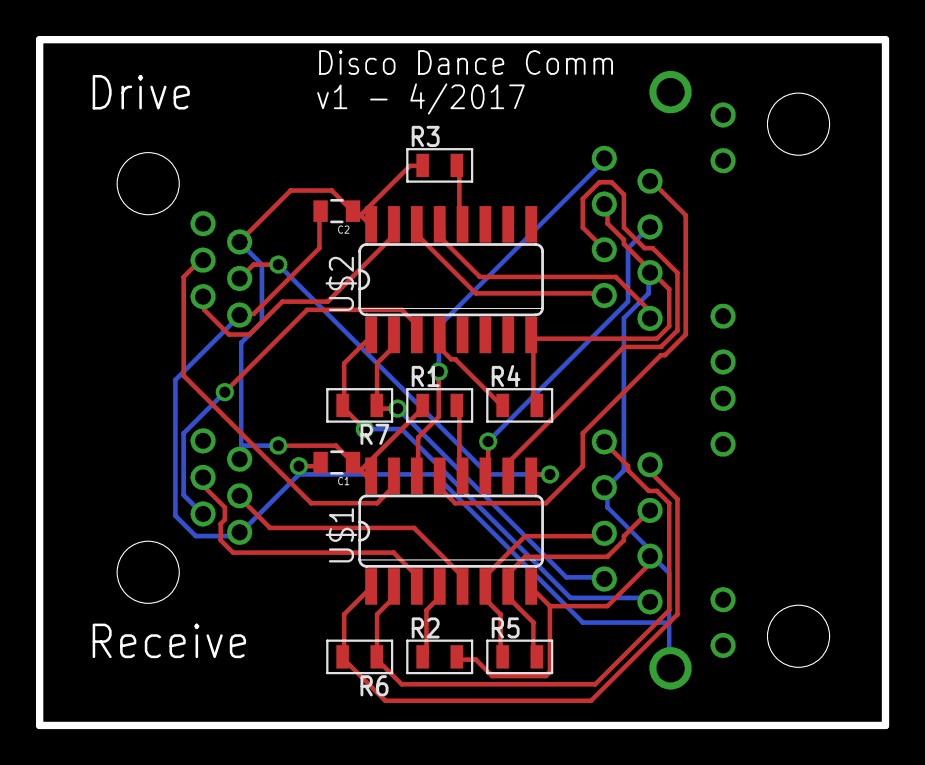
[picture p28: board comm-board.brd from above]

Board: 2 copper layers, 47.0 x 38.1 mm, 13 parts (0 on the bottom side), 24 nets.

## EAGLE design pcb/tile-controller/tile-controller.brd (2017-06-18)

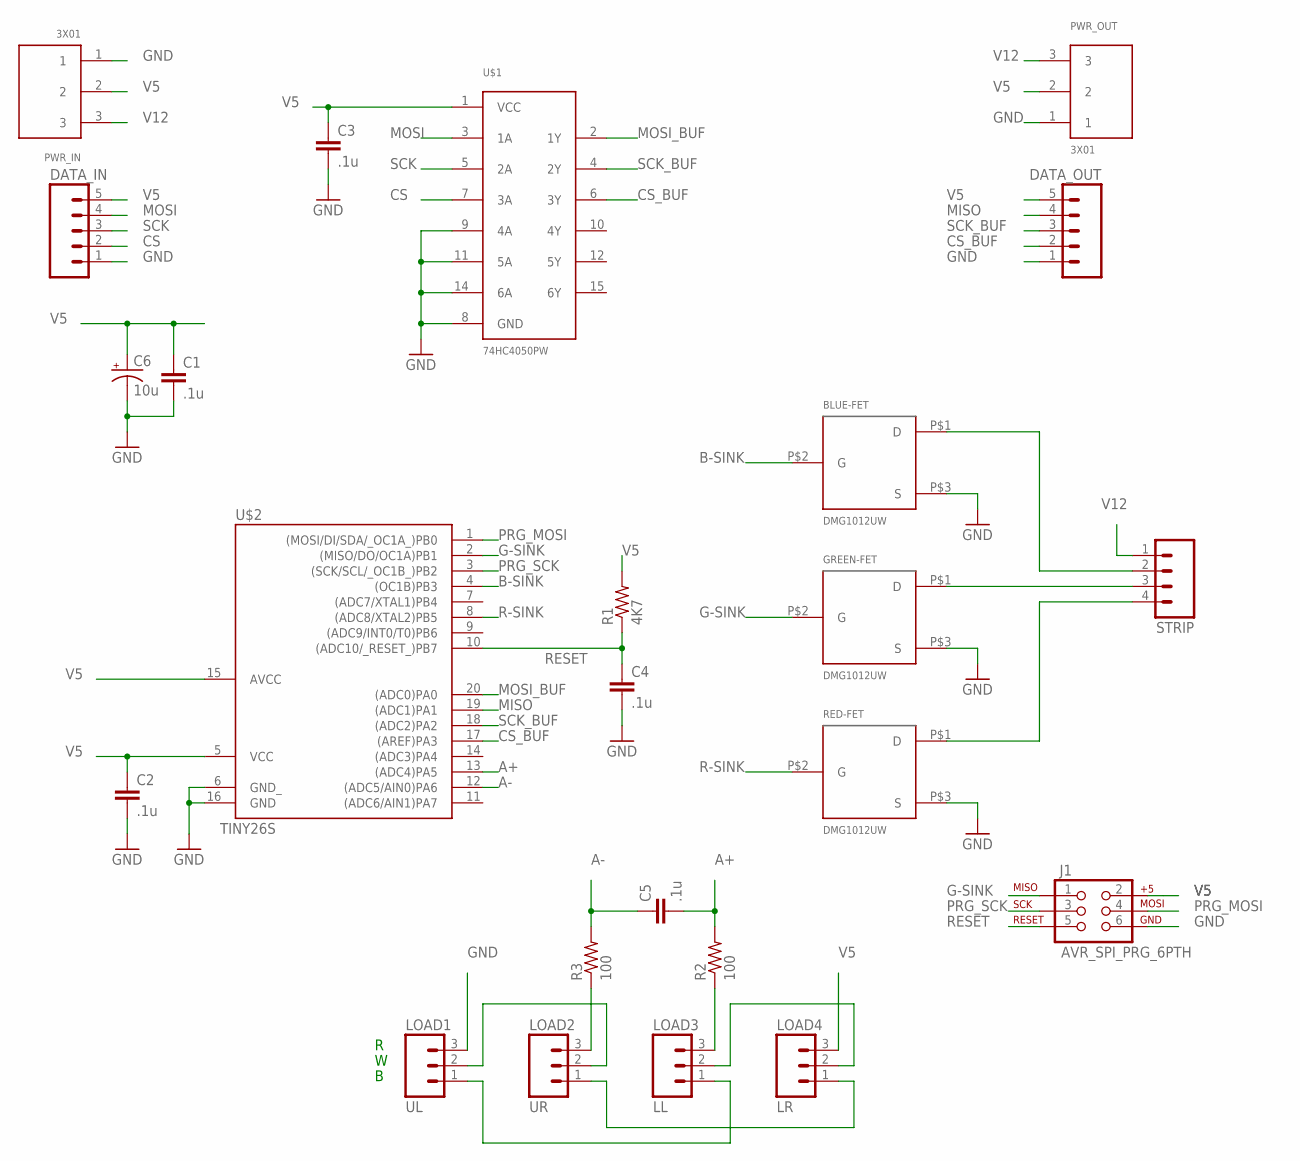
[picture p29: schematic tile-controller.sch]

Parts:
BLUE-FET: DMG1012UW; SOT-323
C1, C2, C3, C4, C5: .1u; 0805
C6: 10u; EIA3216
DATA_IN: M05PTH; 1X05
DATA_OUT: M05PTH; 1X05
GREEN-FET: DMG1012UW; SOT-323
J1: AVR_SPI_PRG_6PTH; 2X3
LOAD1: UL; 1X03
LOAD2: UR; 1X03
LOAD3: LL; 1X03
LOAD4: LR; 1X03
PWR_IN: 3X01; 3X01-18AWG
PWR_OUT: 3X01; 3X01-18AWG
R1: 4K7; 0805
R2, R3: 100; 0805
RED-FET: DMG1012UW; SOT-323
STRIP: M04PTH; 1X04
U$1: 74HC4050PW; TSSOP16.2
U$2: TINY26S; SO20L$

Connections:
A+: C5.2, R2.2, U$2.13 ((ADC4)PA5)
A-: C5.1, R3.2, U$2.12 ((ADC5/AIN0)PA6)
B-SINK: BLUE-FET.P$2 (G), U$2.4 ((OC1B)PB3)
CS: DATA_IN.2, U$1.7 (3A)
CS_BUF: DATA_OUT.2, U$1.6 (3Y), U$2.17 ((AREF)PA3)
G-SINK: GREEN-FET.P$2 (G), J1.1, U$2.2 ((MISO/DO/OC1A)PB1)
GND: BLUE-FET.P$3 (S), C1.2, C2.2, C3.2, C4.2, C6.C (-), DATA_IN.1, DATA_OUT.1, GREEN-FET.P$3 (S), J1.6, LOAD1.3, PWR_IN.1, PWR_OUT.1, RED-FET.P$3 (S), U$1.8 (GND), U$1.9 (4A), U$1.11 (5A), U$1.14 (6A), U$2.6 (GND_), U$2.16 (GND)
MISO: DATA_OUT.4, U$2.19 ((ADC1)PA1)
MOSI: DATA_IN.4, U$1.3 (1A)
MOSI_BUF: U$1.2 (1Y), U$2.20 ((ADC0)PA0)
unnamed: LOAD1.1, LOAD3.1
unnamed: LOAD2.1, LOAD4.1
unnamed: GREEN-FET.P$1 (D), STRIP.3
unnamed: BLUE-FET.P$1 (D), STRIP.2
unnamed: RED-FET.P$1 (D), STRIP.4
unnamed: LOAD1.2, LOAD2.2
unnamed: LOAD3.2, LOAD4.2
PRG_MOSI: J1.4, U$2.1 ((MOSI/DI/SDA/_OC1A_)PB0)
PRG_SCK: J1.3, U$2.3 ((SCK/SCL/_OC1B_)PB2)
R-SINK: RED-FET.P$2 (G), U$2.8 ((ADC8/XTAL2)PB5)
RESET: C4.1, J1.5, R1.1, U$2.10 ((ADC10/_RESET_)PB7)
SCK: DATA_IN.3, U$1.5 (2A)
SCK_BUF: DATA_OUT.3, U$1.4 (2Y), U$2.18 ((ADC2)PA2)
V5: C1.1, C2.1, C3.1, C6.A (+), DATA_IN.5, DATA_OUT.5, J1.2, LOAD4.3, PWR_IN.2, PWR_OUT.2, R1.2, U$1.1 (VCC), U$2.5 (VCC), U$2.15 (AVCC)
V12: PWR_IN.3, PWR_OUT.3, STRIP.1
_1: LOAD2.3, R3.1
_2: LOAD3.3, R2.1

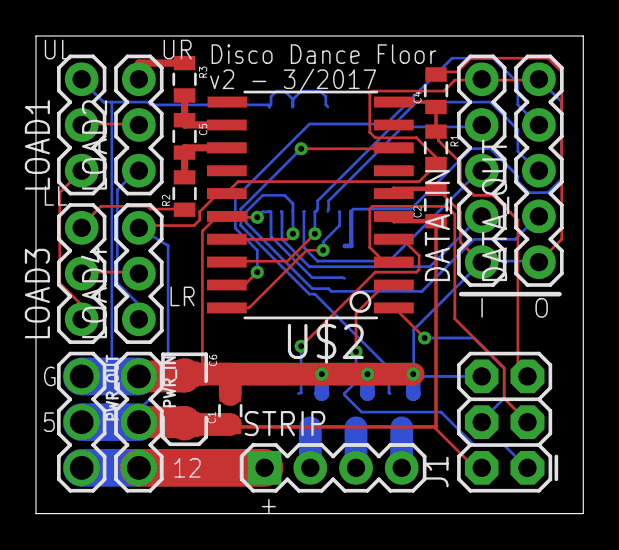
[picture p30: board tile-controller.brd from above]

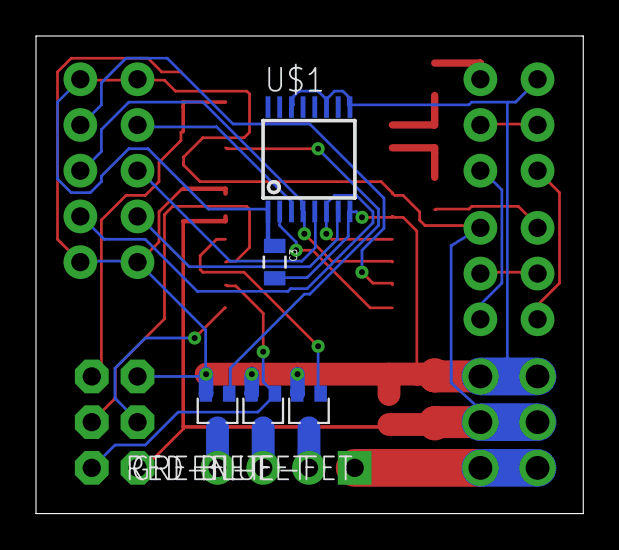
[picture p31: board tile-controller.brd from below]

Board: 2 copper layers, 30.4 x 26.5 mm, 24 parts (5 on the bottom side), 27 nets.

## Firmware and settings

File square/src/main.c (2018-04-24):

/**
 * Code to drive an ATTiny861a
 *
 * http://www.atmel.com/Images/doc8197.pdf
 *
 * - Drives an RGB LED Strip via PWM
 * - Reads 4 load sensors in a wheatstone bridge configuration via differential ADC
 * - Communicates to a master controller via i2c
 *
 */

#include <avr/io.h>
#include <util/delay.h>
#include "main.h"

#define ADC_CONVERSION_DONE() !(ADCSRA & _BV(ADSC))
#define START_ADC_CONVERSION() ADCSRA |= _BV(ADSC)

// Clear the overflow flag after reading data from an SPI transfer
#define CLEAR_OVERFLOW() USISR |= _BV(USIOIF)

// Test whether the overflow condition has happened
#define IN_OVERFLOW() (USISR & _BV(USIOIF))
#define NOT_IN_OVERFLOW() !IN_OVERFLOW()

// Read the value off the chip select
#define CHIP_SELECT() (PINA & _BV(PINA3))
#define IS_CHIP_SELECTED() (CHIP_SELECT() == 0)

// Pull 10-bit values
#define DECODE_RED(byte1, byte2) ((((byte1) & 0x3F) << 4) | ((byte2) >> 4))
#define DECODE_GREEN(byte1, byte2) ((((byte1) & 0x0F) << 6) | ((byte2) >> 2))
#define DECODE_BLUE(byte1, byte2) ((((byte1) & 0x03) << 8) | (byte2))

// Each packet transmitted has 4 bytes.  The dance floor has 64 squares so will need
// to have 64 packets sent to set LED values.  Using 96 to give some extra room
#define DATA_BYTES 4
#define MAX_PACKETS 96

// Hold the data being piped through the squares
uint8_t buffer[DATA_BYTES * MAX_PACKETS];

void init_avr() {
    // Set all of port A to input
    DDRA = 0x00;

    // set all of port B to output
    DDRB = 0xFF;
    PORTB = 0x00;
}

void init_pwm(void) {

    // Set low speed mode (LSM) and start the PLL (PLLE)
    PLLCSR = _BV(LSM) | _BV(PLLE);

    while (!(PLLCSR & 1<<PLOCK));

    // Enable PCKE (set all rather than set bit via |= to save space)
    PLLCSR = _BV(LSM) | _BV(PCKE) | _BV(PLLE);

    // COM1A1 COM1A0 COM1B1 COM1B0 FOC1A FOC1B PWM1A PWM1B
    TCCR1A = _BV(COM1A1) | _BV(COM1B1) | _BV(PWM1A) | _BV(PWM1B);

    // prescaler at 64
    TCCR1B = _BV(CS12) | _BV(CS11) | _BV(CS10);

    // COM1A1S COM1A0S COM1B1S COM1B0S COM1D1 COM1D0 FOC1D PWM1D
    TCCR1C = _BV(COM1A1S) | _BV(COM1B1S) | _BV(COM1D1) | _BV(PWM1D);

    // FPIE1 FPEN1 FPNC1 FPES1 FPAC1 FPF1 WGM11 WGM10
    TCCR1D = _BV(WGM10);

    // Clear the compare counter
    TC1H = 0x00;
    TCNT1 = 0x00;

    // Set the top value of the compare count to 1023
    TC1H = 0x03;
    OCR1C = 0xFF;

    // Timer/Counter0 Control Register B: CS01 & CS00 == clock divided by 64
    TCCR0B = _BV(CS01) | _BV(CS00);

    TCNT0H = 0x00;
    TCNT0L = 0x00;

    // Light the Green LEDs
    set_green(1023);
    set_blue(0);
    set_red(0);

    _delay_ms(1000);

    // Light the Blue LEDs
    set_green(0);
    set_blue(1023);
    set_red(0);

    _delay_ms(1000);

    // Light the Red LEDs
    set_green(0);
    set_blue(0);
    set_red(1023);

    _delay_ms(1000);

    // Clear the LEDs
    set_green(0);
    set_blue(0);
    set_red(0);
}

void init_adc(void) {
    // Enable the ADC (ADEN) and set the prescalar (ADPSX) to 128 which will divide the 16Mhz system
    // clock to a reasonable value for the ADC
    ADCSRA = _BV(ADEN) | _BV(ADPS2) | _BV(ADPS1) | _BV(ADPS0);

    // Set bipolar input mode (BIN), 32x gain (GSEL), see below for MUX5 info
    ADCSRB = _BV(BIN) | _BV(GSEL) | _BV(MUX5);

    // 1.1v reference voltage (REFS1),
    // PA5: positive, PA6: negative (MUX5, MUX3, MUX2, see table 15-5 in datasheet)
    ADMUX = _BV(REFS1) | _BV(MUX3) | _BV(MUX2);

    START_ADC_CONVERSION();
}

void init_spi(void) {
    // USIWM0 sets 3 wire mode, USICS1 sets an external clock source
    USICR = _BV(USIWM0) | _BV(USICS1);

    // Set alternate SPI pins on PORTA (PA0=DI, PA1=DO, PA2=USCK)
    USIPP = _BV(USIPOS);

    // Set PA0 to be an output for the DO SPI function
    DDRA |= _BV(DDA1);

    for (int i = 0; i < DATA_BYTES * MAX_PACKETS; i++) {
        buffer[i] = 0x00;
    }

    // Clear the overflow flag
    CLEAR_OVERFLOW();
}

void set_blue(uint16_t val) {
    TC1H = val >> 8;
    OCR1D = val & 0x0FF;
}

void set_red(uint16_t val) {
    TC1H = val >> 8;
    OCR1A = val & 0x0FF;
}

void set_green(uint16_t val) {
    TC1H = val >> 8;
    OCR1B = val & 0x0FF;
}

void handle_spi(void) {
    uint8_t transferred = 0;
    uint8_t val_in;

    // Start the head at 4 since 0..3 are the weight values
    uint16_t head = 4;

    // When we enter this method USIDR already has buffer[head-4] loaded.  When we
    // write out val_out it will be for the next byte, which is buffer[head+1-4] or buffer[head-3]
    uint8_t val_out = buffer[head-3];

    // Wait for the next cycle to start
    while (!IS_CHIP_SELECTED());

    // While in chip select, read data
    while (IS_CHIP_SELECTED()) {
        transferred = 1;

        // Wait for bytes to be read in, at which point overflow will trigger
        while (NOT_IN_OVERFLOW() && IS_CHIP_SELECTED());

        // Read the value we got in and immediately write out the value we want to send forward
        val_in = USIDR;
        USIDR = val_out;
        CLEAR_OVERFLOW();

        // Write the value we got to the head of the fifo
        buffer[head] = val_in;
        head++;

        // Set the value we'll output on the next round.  Now that head has been incremented, the
        // value in USIDR is buffer[head-4].  To ready the next value we grab buffer[head+1-4]
        val_out = buffer[head-3];
    }

    // If we didn't just transfer some bytes, don't decode and set LEDs
    if (!transferred) {
        return;
    }

    // The value of head is incremented after the last byte is written, and then incremented again when
    // chip select goes high (not selected) for this reason the last byte written is at head - 2
    uint16_t red = DECODE_RED(buffer[head-5], buffer[head-4]);
    uint16_t green = DECODE_GREEN(buffer[head-4], buffer[head-3]);
    uint16_t blue = DECODE_BLUE(buffer[head-3], buffer[head-2]);

    set_red(red);
    set_green(green);
    set_blue(blue);
}

void handle_adc(void) {

    if (ADC_CONVERSION_DONE()) {
        // These MUST be read in this order, ADCL then ADCH "to ensure that the
        // content of the data registers belongs to the same conversion"
        buffer[1] = ADCL;
        buffer[0] = ADCH;

        buffer[2] = 0;
        buffer[3] = 0;

        // Ready the first byte for the next transfer
        USIDR = buffer[0];

        START_ADC_CONVERSION();
    }
}

void sync_spi(void) {
    // Wait out a full cycle to make sure we are fully synced up

    // Wait for any current cycle to finish
    while (IS_CHIP_SELECTED());

    // Wait for the next cycle to start
    while (!IS_CHIP_SELECTED());

    // Wait out this cycle
    while (IS_CHIP_SELECTED());
}

int main(void) {
    init_avr();
    init_pwm();
    init_adc();
    init_spi();

    // Get ourselves synced up by waiting out one cycle
    sync_spi();

    while (1) {
        handle_spi();
        handle_adc();
    }
}

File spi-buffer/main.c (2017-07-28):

/**
 *
 */

#include <avr/io.h>
#include <util/delay.h>
#include "main.h"

// define baud
//#define BAUD 9600
#define BAUD 57600

// set baud rate value for UBRR
#define BAUD_RATE ((F_CPU/(16*BAUD))-1)

#define PWR_LED PIN0
#define TX_LED PIN1

#define POWER_LED_ON PORTC |= _BV(PWR_LED)
#define POWER_LED_OFF PORTC &= ~_BV(PWR_LED)

#define TX_LED_ON PORTC |= _BV(TX_LED)
#define TX_LED_OFF PORTC &= ~_BV(TX_LED)

#define DDR_SPI DDRB
#define DD_MISO DDB3

// Read the value off the chip select
#define CHIP_SELECT() (PINB & _BV(PINB2))
#define IS_CHIP_SELECTED() (CHIP_SELECT() == 0)

// Each packet received has 4 bytes.  The dance floor has 64 squares so will send 64 packets
// of weight values * 4 byes == 256 bytes.  Using 96 packets to give some extra room
#define DATA_BYTES 4
#define MAX_PACKETS 96

// Hold the data being piped through the squares
uint8_t buffer[DATA_BYTES * MAX_PACKETS];
// Keep track of where we're at in the buffer
uint16_t head;

void init_avr() {
    // Set PC0 and PC1 as outputs
    DDRC = _BV(DD0) | _BV(DD1);
    PORTC = 0x00;
}

/**
 * Initialize UART
 */
void init_uart() {
    // Set baud rate
    UBRR0H = 16 >> 8; // BAUD_RATE >> 8;
    UBRR0L = 0xFF & 16; // BAUD_RATE;

    // Enable receiver and transmitter
    UCSR0B = _BV(TXEN0) | _BV(RXEN0);

    // 8bit data format
    UCSR0C = _BV(UCSZ00) | _BV(UCSZ01);
}

void init_spi() {
    // Set MISO output, all others input
    DDR_SPI = _BV(DD_MISO);

    // Enable SPI
    SPCR = _BV(SPE);

    for (int i = 0; i < DATA_BYTES * MAX_PACKETS; i++) {
        buffer[i] = 0x00;
    }
    head = 0;
}

/**
 * Send one byte of data
 *
 * @param data
 */
void uart_transmit(unsigned char data) {
    // wait while register is free
    while (!(UCSR0A & _BV(UDRE0)));

    // load data in the register
    UDR0 = data;
}

void spi_receive() {
    head = 0;

    // Block until some data comes our way
    while (!IS_CHIP_SELECTED());

    // Once the data comes, keep reading until it stops
    while (IS_CHIP_SELECTED()) {
        // Wait for reception to complete, but don't get hung here if chip select is no longer active
        while (!(SPSR & _BV(SPIF)) && IS_CHIP_SELECTED());

        // Make sure we left the loop above because data arrived
        if (IS_CHIP_SELECTED()) {
            buffer[head++] = SPDR;
        }
    }
}

void send_to_host() {
    // Move through the buffer four bytes at a time.  Only the first two bytes will
    // contain data.  The rest should be zero to pad out the SPI frame size
    for (int i = 0; i < head; i += 4) {
        uart_transmit(buffer[i]);
        uart_transmit(buffer[i+1]);
    }
    uart_transmit_stop();
}

void uart_transmit_stop() {
    // Data received is always 4 bytes, but only the first two bytes ever have data.  And then, only the
    // first two bits of the first byte will ever be set.  This sequence should never naturally be received
    uart_transmit((unsigned char) 0xFF);
    uart_transmit((unsigned char) 0xFF);
}

int main() {
    init_avr();
    init_uart();
    init_spi();

    POWER_LED_ON;

    while (1) {
        spi_receive();

        TX_LED_ON;
        send_to_host();
        TX_LED_OFF;
    }
}

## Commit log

2017-02-03 Code to measure differential ADC and light the lights according to the result
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2017-02-26 Got i2c working (but buggy) and cleaned up code a bit
    [main.c]
2017-03-28 Moved previous code into a proof of concept folder. Created new attempt (not using interrupts) in the square folder.
    This should allow additional folders for the 2 SPI XMEGA that will control all the squares
2017-03-29 Added a "make fuse" so I don't have to remember the fuse settings anymore or grep them from history
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2017-06-18 Adding in eagle files
    [DRILEGEND.CFG, pi-shield.brd, pi-shield.sch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]
2017-06-18 Additional board
    [comm-board.brd, comm-board.dxf, comm-board.sch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]
2017-06-18 Renamed Pi Shield
    [pi-shield.brd, pi-shield.sch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]
2017-06-19 8mm trace width/separation version of the pi shield
    [pi-shield.brd, pi-shield.sch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]
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2017-07-05 Two updates:
    * Update set LED methods to reflect the actual colors they control
    * Reduce operations done between reading value and setting next value in USIDR as much as possible
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2017-07-10 Fix some handling for the Raspberry driver. Also add some debugging code for now.
2017-07-10 OOF. Switch uint8_t to uint16_t since the value of head will exceed 256.
    This was causing garbage data to be passed along as head flipped back to 0 and started transmitting values from
    the beginning of the buffer.
    [main.c]
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2017-07-23 Several fixes to get weights working.
    * Taking lowest weight value seen over a particular pariod out of a number of samples to use a the weight value floor.
    * Treating any weight value under a certain amount as zero to eliminate noise
    * Upped BAUD rate so that foot steps are more responsive
    * Fixed some initialiation problems (array overruns)
    * Making sure we don't load Raspberry modules when we are running w/ OPC
2017-07-23 Upped baud rate. Updated constant with correct value but then computed it because didn't trust the math was happening correctly. Should fix this but wedding is comming up and have bigger fish to fry
    [main.c]
2017-07-23 floor: add a simple local webserver ("devserver") driver.
    Same idea as the OPC driver, just runs in a web browser and rendered with
    HTML/CSS.
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2017-07-23 Don't explicitly load any drivers so non-raspberry hosts don't have to load libs they don't need or can't install (serial driver stuff for the pi)
2017-07-24 api: bugfix: return playlist remaining time in millis.
2017-07-27 Output the driver name and its max led value on start up
2017-07-28 Update the SPI buffer to only send the two bytes of weight information, rather than pass along the full four bytes it gets from the floor.
    Two of the four bytes will always be zero, so there's no need to transmit them. Since the two bytes represent a
    10-bit value, only 10 of the 16 bits in those two bytes are used, so we still have a valid stop condition (0xFF, 0xFF)
    Finally, handle serial synchronously rather than running a thread. Running a thread seemed to cause problems and made things more
    complex to program and debug. Its main goal was to make sure we weren't blocked on IO when we could be rendering a frame but that
    doesn't seem to be an issue.
    [main.c, serial_read.py]
2017-07-28 Read as much data as is available every cycle.
    Filter out values if the history of past values is sketchy (any previous is zero) to reduce "ghost steps"
2017-07-28 Added ability to start/stop the playlist
    This is useful for setting up the floor since there are some
    syncing issues around the data sent to the floor. If the floor is powered on while data is
    being sent it can easily get offset/shifted from the encoded data stream and decode starting
    at the wrong place. The result is that the lights freak out. The fix is to stop the show, repower the floor
    and then start the show again.
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2017-08-12 Adding models of dance floor
    [3-8+wing+nut.skp, Exploded View Tile.skp, Floor Assembly.skp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]
2017-10-15 Removed most references to the opc driver
    The OPC driver has been superseded by the devserver which is way better.
2018-04-26 Test with normal ADC and no odd off by 3 first frame from SPI
    Got this all working. Checkpointing
2018-08-26 Remove all tare functionality.
    It should no longer be necessary after new weight sensors.
2018-08-26 Make sure the server doesn't die if the floor is powered on after the server is running.
2018-08-27 Updated eagle version and added text labels R, W, B (red, white, black) for the weight input wire
    [tile-controller.sch]
2018-09-17 tests: add `nosetests` and friends; update non-tests to not break.
    The test runner will load many modules (like `test-pattern.py`) in
    the course of probing each for test cases. Because of this, the
    `sys.exit(0)` calls were aborting the `nosetests` command. Such
    modules have been neutralized by guarding their behavior behind
    `main()` functions.
    [nose.cfg]
2018-09-18 Committing change to this file though it was probably just a perspective change /shrug
    [Exploded View Tile.skp]
2018-09-18 tests: run all processors under test; fix stuff i broke :(
    The test could be extended to fuzz more states and inputs,
    like weights. Currently it is rudimentary but at least would
    catch oblique crashes.
2018-09-30 Update to account for new style weight sensors.
    New weight senors have a 10-bit range and will not return negative values. Remove 2's compliment conversion, simplify processing and add a threshhold that measures a step rather than filting noise.
2018-09-30 The OPC driver is no longer necessary
2018-09-30 Update imports across project.
    * Add floor. to imports where necessary
    * Change ordering of imports to list global imports first, project local second.
    * Fix any PEP warnings
    [color_utils.py, flash_bang.py]
2018-10-01 Fix driver name and pass required default value
2018-10-22 floor: processor: auto-register processors.
    Removes the silly boilerplate we had gotten in to when
    defining new processors. Also adds a unitest which ensures all
    the processors in the default playlist are resolvable.
    Currently assumes (a) all processors reside in the `processor`
    submodule, and (b) all processor class names are globally unique;
    which seem like safe enough assumptions for a while.
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2018-12-26 floor: refactor: clean up interfaces between show & controller.
    Primarily, injects `driver` into `Controller` to facilitate simpler
    testing/mocking in the future.
2018-12-26 First version of a "floor heat" pattern.
    Responds to foot steps, floor "heats up" the more people are dancing on it.
2018-12-26 A version of spiral that is locked to 1 frame per beat.
    Not really part of the foot responsive patterns but wanted to get this checked in as its been floating here for a while
2018-12-27 processors: use `context.clock` instead of `time.time()`.
    Making processors use our own clock means:
    * Processors are insensitive to drift or changes in “wall time”.
    * Clock can easily be injected for testing and/or profiling.
    * Clock can be artificially sped up or slowed down, e.g. to achieve a faster/slower rendering effect.
    It also means fewer syscalls during execution, e.g. only one call
    site fetching system time, but that’s likely a micro-optimization.
2018-12-27 Several updates to the heat step:
    * Update it to be HSV based internally to allow easier color shifts
    * Link up color shifting to a control
    * Link saturation shifting to a control
    * Link up heating and cooling to control
    * Added HSV to RGB conversions to the Base class
    * Fixed devserver max color value
2018-12-29 Fix unit tests, fix from unit test, update Heat/SimpleStep after merge from master
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2019-01-21 processor: remove explicit `set_bpm()` callback.
    It turns out no current processor needed the callback, so this
    change opportunistically simplifies/reduces the affected interfaces.
2019-01-21 driver: convert weights to a fixed scale of `0.0 - 1.0`
    This removes `max_floor_value` from the driver/controller interface;
    drivers are responsible for converting any native weight values to
    this range.
2019-01-21 driver: use a fixed scale for color values; add brightness api.
    This removes `get_max_led_value()` from the driver interface; instead,
    all drivers and processors return pixels on a fixed scale.
2019-01-21 controller: static fps (2/2): clamp processors to desired fps.
    The previous change boosted the call rate for `get_next_frame()` to
    120/sec globally. But most existing processors were written to
    expect the call rate they defined in `self.fps`, and so such
    processors now render too fast.
    This change restores that functionality but accomplishes it
    differently, by extending the `@clocked()` decorator to accept
    a `frames_per_second` clamp.
    [flash_bang.py]
2019-01-21 controller: ensure pixels are ints on range [0, COLOR_MAXIMUM]
    Some processor were returning floating point values. Some of these
    pixels had very small non-zerovalues (eg 1e-14) which in turn broke
    the “black pixel” test of `blend_pixel_copy`.
    [color_utils.py]
2019-01-26 cleanup: replace `Processor.max_value` with `COLOR_MAXIMUM`
    As of #44 the color scale is global and does not vary (outside
    of driver implementations), so there is no instance-level use for
    `self.max_value`. Purely mechanical cleanup.
    [flash_bang.py]
2019-04-06 py2to3: futurize stage1 automatic changes.
    Command:
    ```
    futurize --write --stage1 floor/**/*.py
    ```
2019-04-06 py2to3: futurize stage2 fixes.
    futurize --write --stage2 -x libfuturize.fixes.fix_division -x libfuturize.fixes.fix_division_safe --nobackups floor/**/*.py
    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
    [color_utils.py, easing.py]
2019-06-02 rendering: fix blending logic; add test.
    Removes the unnecessary `leds` parameter on `RenderContext.render`
    [color_utils.py]
2019-06-08 controller: make fader/switch events distinct per layer
    State for ranged values is moved into each RenderLayer.
    This effectively means we can build distinct controls, in midi
    and the web UI, for each individual layer.
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2019-08-23 bugfix: fix processors which were not scaling color values
    I noticed Zap, Throbber, and Animator were outputting some dim patterns.
    It looks like a bug I introduced when refactoring colors in #46.
    The bug is these processors were defining colors on (0, 256) and
    never rescaling them.
    To fix this & hopefully avoid similar bugs in the future, updated
    `hex_to_rgb` to return properly scaled colors; and deleted the scaling
    from the `get_pallet` / `get_random_pallet` interfaces since there
    were no callers that need to provide a different scale.
    Moved some helper methods `tint()` and `shade()` into color utils
    while I was in the area.
    [color_utils.py]
2019-09-02 Added a new layout for single pod testing.
    This cascaded in a few other depenent fixes/cleanups
    [serial_read.py]
2019-09-05 Fix `black_is_alpha` behavior broken in #54
    [color_utils.py]
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2019-09-24 Fix some initialization issues
    * If args.driver_names is not given, it amounts to set(None) which is still true and is used rather than the defaults
    * The loop should iterate over driver_names
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2025-04-24 Update README.md
    Oh jesus christ, ' poetry env activate' only prints the commend to use to activate the environment, it doesn't actually run it. What an extremely fussy implementation.
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2025-04-26 Pull in changes made so far (#76)
    * Add additional logging, also document argument inputs better
    * Make sure we set an explicit data rate.
    Also add some handling to wait for data to return from the floor for one
    shot scripts
    * Change the eagle directory to more general "pcb"
    [DRILEGEND.CFG, comm-board.brd, comm-board.dxf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]
2025-04-26 Migrate pcb files from Eagle to KiCad (#77)
    * New .gitignore and checkin updated kicad files for the comm-board
    * Adding updated files for the pi-shield in KiCad
    * Update tile-controller to KiCad
    [comm-board.kicad_pcb, comm-board.kicad_sch, pi-shield.kicad_pcb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]
2025-04-26 Add models and updates that never made it into git
    [Single tile.skp, Weight Sensor.skp]
2025-04-26 Added STL versions of all the files
    [Exploded View Tile.stl, Hardware 1.4 Nuts Bolts Adjustable Length.skp, Hardware 1.4 Nuts Bolts Adjustable Length.stl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]
2025-08-28 Tile stability improvements (#78)
    * Clear the USI counter after chip select goes low
    Very hopeful this will fix the instability issues with the tile. When the floor gets in this state it seems like its not shifting data along the 4 byte boundary for each square. My theory is that the enable line goes high (disabled) before a full byte is read in to the USIDR register, leaving behind partial data and a starting point in the middle of the register when the next byte is sent. ONce this happens, it will be off by X until the floor is power cycled.
    By clearing the USI counter after select goes high, regardless of what we read in, it should guaruntee that we're in a good, known state to accept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
    [main.c]
2025-08-28 Upodate with some fixes found in testing with the floor.
    [serial_read.py]
2025-09-05 floor: switch to ruff for python linting/formatting, part 1
    - perform all automatic/safe fixes
    [color_utils.py]
2025-09-05 floor: switch to ruff for python linting/formatting, part 2
    - perfom all "unsafe" fixes (`poetry run ruff check --fix --unsafe-fixes`)
    [color_utils.py]
2025-09-05 floor: switch to ruff for python linting/formatting, part 3
    - manual fixes
2025-09-05 floor: fix up build scripts
    [nose.cfg]

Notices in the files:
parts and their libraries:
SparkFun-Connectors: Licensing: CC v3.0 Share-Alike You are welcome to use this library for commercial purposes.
